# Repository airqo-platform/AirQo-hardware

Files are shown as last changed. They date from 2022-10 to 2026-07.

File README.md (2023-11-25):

# AirQo-hardware
The AirQo air qaulity monitoring device is an IoT connected device that provides realtime measurement of particualte matter concetrations and environmental readings (atmospheric pressure, relative humidity and temperature). the devices is powered by a Li-ion battery and connects to the iinternet over a 2g GSM network.
## Folder Structure
-[**Firmware**](./firmware)
    -Contains the various firmware projects for AirQo hardware, specific to different build environments
-[**Hardware**](./hardware)
    -Contains the hardware designs for AirQo hardware, 3d modesl for 3d printing, Schematic and PCB designs
-[**docs**](./docs)
    -Contains relevant documentations and templates
## Hardware design
The device is currently designed around an [Atmega2560](https://ww1.microchip.com/downloads/aemDocuments/documents/OTH/ProductDocuments/DataSheets/ATmega640-1280-1281-2560-2561-Datasheet-DS40002211A.pdf) microcontroller, that hosts the device firmware.
### block diagram 
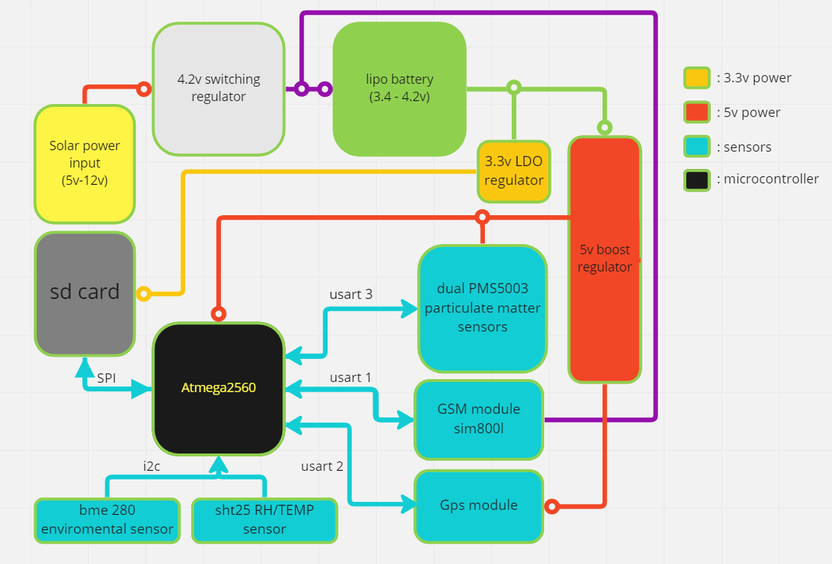
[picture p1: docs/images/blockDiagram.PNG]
block diagram

### Sensors
*Particulate matter sensors [Plantower Pms5003]()

*Environmenatal sensors     [BME280](),[SHT25]()

*GPS                        [NEO6-GPS-module]()

*Communication              [Sim800l-GSM-GPRS]()

### CAD tools
list of tolls used to design the airqo monitor
pcb tools, 3d tools, links to design files here on github
f
## Firmware design
### developed with cpp and arduino framework
The firmware provides the airqo monitor with a number of features
*Realtime measurements of particualte matter concetrations
*Logging of data to local storage
*Over The Air Firmware Updates (OTA)
## License
This project is licensed under the MIT License - see the [LICENSE.md](LICENSE.md) file for details

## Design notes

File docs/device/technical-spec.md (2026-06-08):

# Technical Specification

---

## 1. General Technical Specifications

| Parameter | Value |
|---|---|
| **Main Controller** | ATMEGA2560 |
| **Storage** | 256KB built-in, expandable to 32GB with external SD-Card |
| **RAM** | 2KB |
| **Battery** | 3240 mAh |
| **Charging** | Solar panel input 5–12V · 5V USB micro input |
| **Connectivity** | 2G GSM, Wi-Fi, LoRaWAN |
| **Dimensions** | 147.5 × 71.5 × 7.4 mm |
| **Weight** | 172 g |

!!! note
    These specifications are subject to change based on product updates and variations.

---

## 2. Electrical Specification

| Parameter | Value |
|---|---|
| **Input Voltage** | 5–12V |
| **Battery** | 3.7V LiPo 3.5AH *(solar-powered monitors)* · 3.7V Li-ion 8.8AH *(mobile monitors)* |
| **Power consumption** | 1.1W normal use · 0.098W save mode |
| **Current Draw** | 220mA normal use · 19.6mA save mode · 300mA during transmission |
| **Solar Panel** | 6W max power · 1.2A operating current · 5V operating voltage · 1.15A open circuit current · 6V open circuit voltage |

---

## 3. Communication Interfaces

| Parameter | Value |
|---|---|
| **Technology & Frequency** | Quad-band GSM/GPRS 2G — GSM 850MHz, EGSM 900MHz, DCS 1800MHz, PCS 1900MHz |
| **Data Accessibility** | AirQo Dashboard · AirQo API · AirQo App |

---

## 4. Technical Drawings

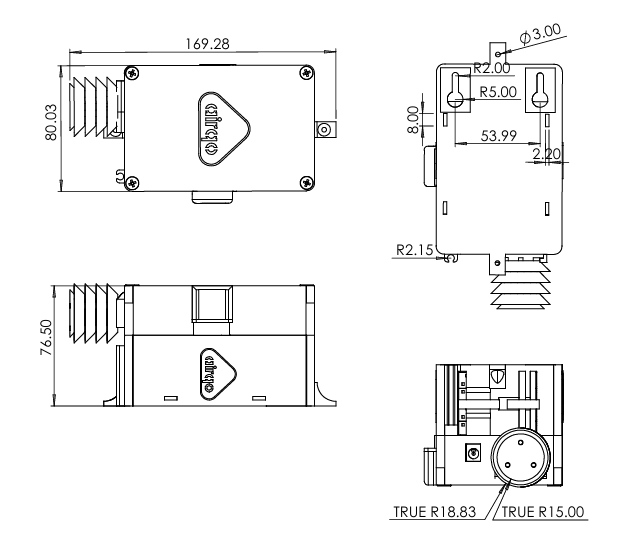
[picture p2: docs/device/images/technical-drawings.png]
Technical Drawings


For detailed PCB schematics and 3D models, see the [hardware folder](https://github.com/airqo-platform/AirQo-hardware/tree/main/hardware) in the repository.

---

## Related Pages

- [Device Overview](overview.md) — Device features and air quality measurement specs
- [Firmware Overview](../firmware/overview.md) — Firmware architecture

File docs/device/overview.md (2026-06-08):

# Device Overview

> **Tags:** Onboarding, Technical Support

---

## Know Your Monitor

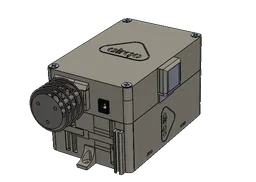
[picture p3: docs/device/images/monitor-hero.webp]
AirQo Binos Air Monitor


The **Binos Air Monitor** is a low-cost air quality monitor that measures Particulate Matter PM2.5 and PM10, as well as ambient environmental parameters (temperature and humidity). The device is designed for deployment in urban and peri-urban environments to deliver real-time air quality data to the AirQo analytics platform.

The monitors are optimized with capabilities to cope with challenges like extreme weather conditions including high levels of dust, humidity and temperature fluctuations common in Sub-Saharan Africa.

Powered by either mains or solar, the device is optimized to work in settings characterized by unreliable power and internet connectivity.

---

## Main Features

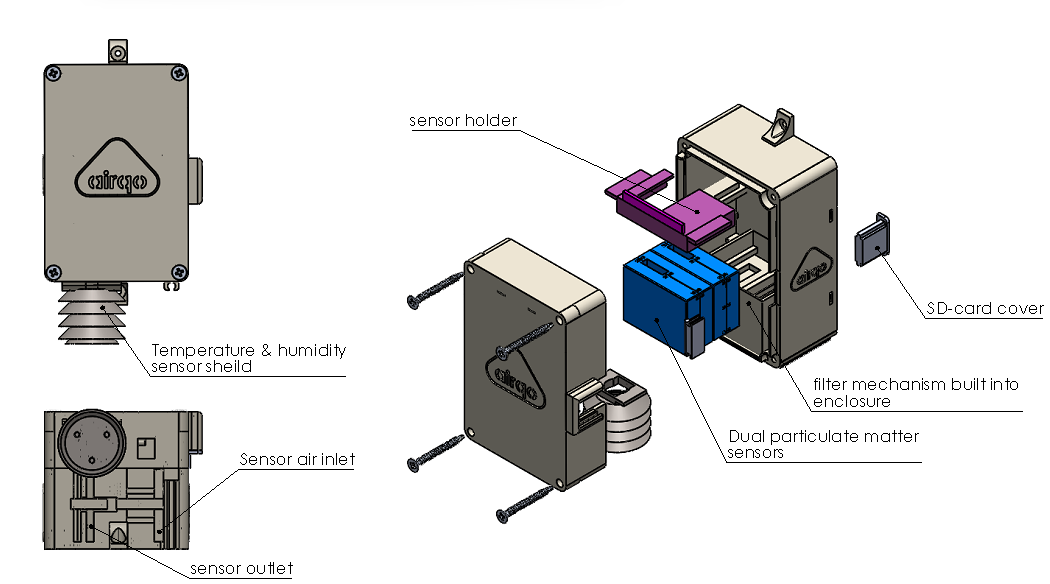
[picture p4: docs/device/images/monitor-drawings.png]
AirQo Monitor Drawings


| Feature | Detail |
|---|---|
| **Main Controller** | ATMEGA2560 |
| **Storage** | 256KB built-in, expandable to 32GB via micro SD-Card |
| **RAM** | 2KB |
| **Battery** | 3240 mAh |
| **Charging** | Solar panel input 5–12V · 5V USB micro input |
| **Connectivity** | 2G GSM, Wi-Fi, LoRaWAN |
| **Dimensions** | 147.5 × 71.5 × 7.4 mm (5.8 × 2.8 × 0.3 in) |
| **Weight** | 172 g (6.07 oz) |

---

## Air Quality Measurements

| Parameter | Specification |
|---|---|
| **Particulate matter range** | 0.3–1.0 μm · 1.0–2.5 μm · 2.5–10 μm |
| **Effective range (PM2.5)** | 0–500 μg/m³ |
| **Maximum range (PM2.5)** | < 1000 μg/m³ |
| **Consistency (PM2.5)** | ±10% @ 100–500 μg/m³ · ±10 μg/m³ @ 0–100 μg/m³ |
| **Standard volume/flow** | 0.1 L |
| **Single response time** | < 1 s |
| **Data resolution** | 60–90 seconds |

---

## Related Pages

- [Technical Specification](technical-spec.md) — Full hardware specifications
- [Firmware Overview](../firmware/overview.md) — How the firmware operates
- [Deployment](../deployment.md) — How to deploy and access data

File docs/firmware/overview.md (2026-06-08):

# Firmware Overview

Robustly developed firmware enables efficient operation of the device to deliver the best data availability and quality to the users. This section covers the key firmware features and how they work.

---

## Key Firmware Features

### Sensor Sampling

The device obtains meteorological (temperature and humidity) and other sensing parameters like particulate matter and battery voltage using different sensor modules. Parameters sampled include:

- PM2.5
- PM10
- Temperature
- Humidity
- Battery voltage

### SD Card Data Logging

The data obtained from the sensors is logged onto a micro SD card in CSV file format with the necessary parameters to be sent to the cloud storage. This ensures data is not lost even when network connectivity is unavailable.

See [SD Card Data Organization](sd-card.md) for details on how data files are structured.

### Automatic Time Tracking

Device firmware utilizes a Real Time Clock (RTC) to track the date and time with accuracy. A backup battery powers the RTC to provide time tracking even when the main battery is depleted.

The RTC time domain informs the following parameters:

- Local filenames stored on the SD card (based on time of creation)
- Device data timestamps (based on the time of writing to the SD-card file)

### Transmission Failure Handling

The device firmware incorporates data transmission failure handling by buffering data entries that have failed in transmission to a backup file and scheduling retransmission. This ensures no data loss during periods of poor connectivity.

---

## Firmware Variants

| Variant | Description | Folder |
|---|---|---|
| **AirQo Rev C** | Standard production firmware (GSM/GPRS) | [`airqo_rev_c_firmware`](https://github.com/airqo-platform/AirQo-hardware/tree/main/firmware/airqo_rev_c_firmware) |
| **LoRaWAN v1** | For LoRaWAN network deployments | [`lorawan_firmware_v1`](https://github.com/airqo-platform/AirQo-hardware/tree/main/firmware/lorawan_firmware_v1) |
| **MQTT / ThingSpeak** | For MQTT-based integrations | [`mqtt_thingspeak_bi_directional_communication`](https://github.com/airqo-platform/AirQo-hardware/tree/main/firmware/mqtt_thingspeak_bi_directional_communication) |

---

## Related Pages

- [SD Card Data Organization](sd-card.md)
- [Firmware Configuration](configuration.md)
- [Technical Specification](../device/technical-spec.md)
- [Deployment](../deployment.md)

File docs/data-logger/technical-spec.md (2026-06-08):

# Data Logger — Technical Specification

---

## General

| Parameter | Value |
|---|---|
| **Certifications** | None |
| **Dimensions** | 112.85 × 55.18 × 54.86 mm |
| **Weight** | 215.5 g |
| **Deployment setting** | Outdoor / ambient conditions |
| **Operating temperature** | 0–45 °C |

!!! warning
    Not compatible with fire, flames, or immersion in water.

---

## Host Interface

| Port | Type |
|---|---|
| CS I/O communications port | — |
| RS-232 serial port | DB9 male |
| RS-485 serial port | DB9 female |
| USB | Version 2.0 with USB-C connector |

---

## Power

| Parameter | Value |
|---|---|
| **Input voltage** | 5–12V |
| **Battery** | 3.7V Li-ion 3.5AH |
| **Power — Active** | 1.1W |
| **Power — Save mode** | 0.098W |
| **Current draw — Normal use** | 220mA |
| **Current draw — Save mode** | 19.6mA |
| **Current draw — Transmission** | 300mA |

---

## Cellular Communication

| Parameter | Value |
|---|---|
| **Network technology** | Quad-band GSM/GPRS 2G |
| **Frequencies** | GSM/GPRS 850MHz · GSM EDGE 900MHz · DCS 1800MHz · PCS 1900MHz |
| **Data accessibility** | AirQo Dashboard · AirQo API · AirQo App |

---

## Data Speeds

| Technology | Download | Upload |
|---|---|---|
| LTE | Max 10 Mbps | Max 5 Mbps |
| WCDMA | Max 384 Kbps | Max 384 Kbps |
| GSM GPRS | Max 107 Kbps | Max 85.6 Kbps |
| GSM EDGE | Max 296 Kbps | Max 236.8 Kbps |
| RS-232 / RS-485 | 9600 bps – 460.8 Kbps | 9600 bps – 460.8 Kbps |

---

## Technical Drawings

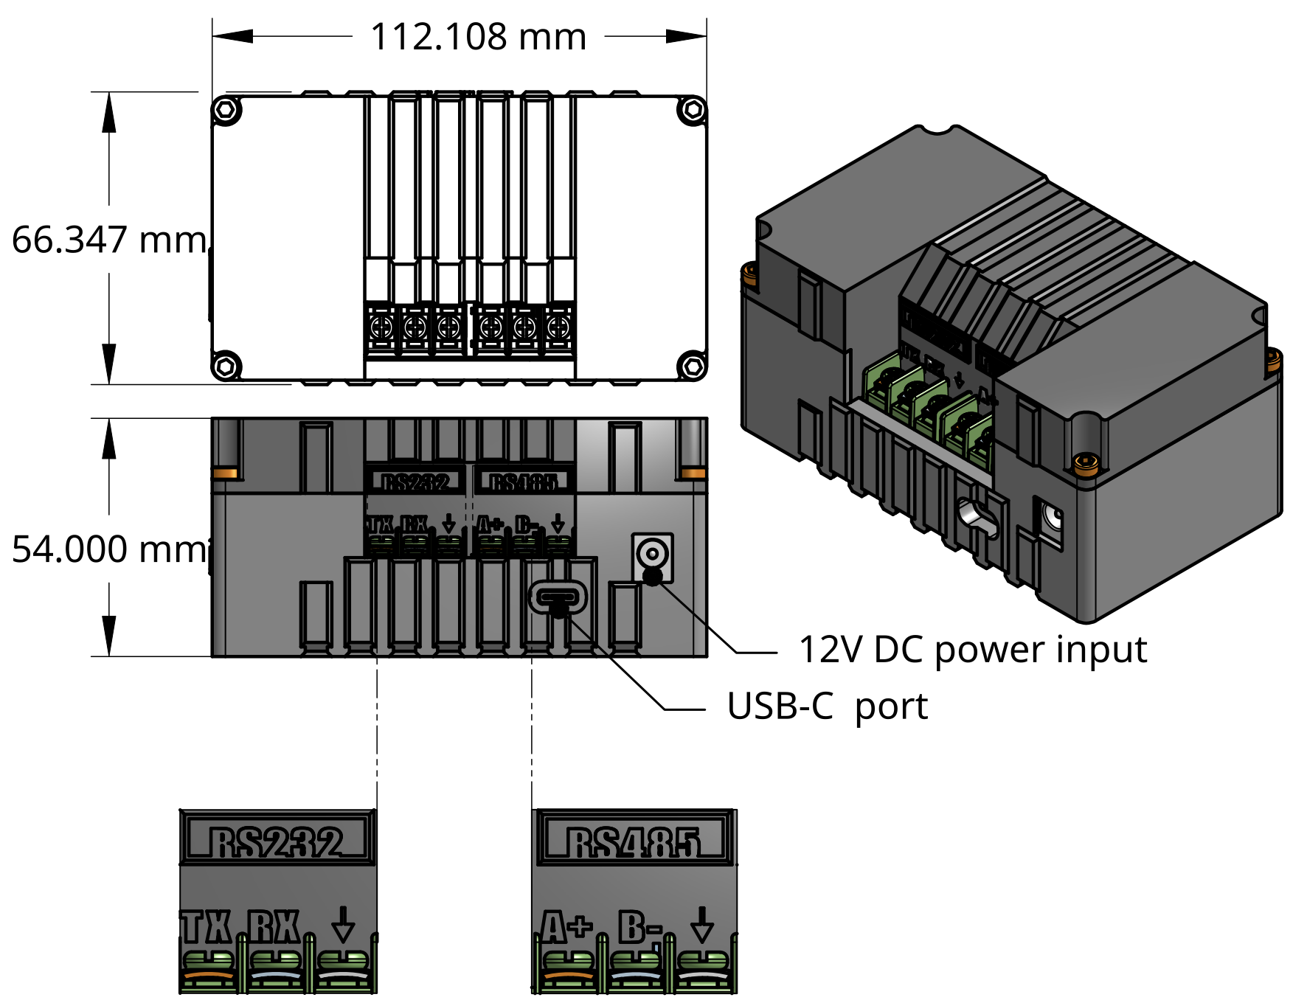
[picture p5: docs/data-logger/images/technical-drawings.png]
Technical Drawings


---

## Related Pages

- [Data Logger Overview](index.md)
- [Installation](installation.md)
- [Data Access](data-access.md)

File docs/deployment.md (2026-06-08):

# Deployment Guide

This provides information on how to deploy the AirQo device onto the AirQo analytics platform successfully. This section guides on installing the monitor using the included toolkit. Mounting equipment for pole, wall, or face installation is provided along with step-by-step guidance.

---

## Installation Toolkit

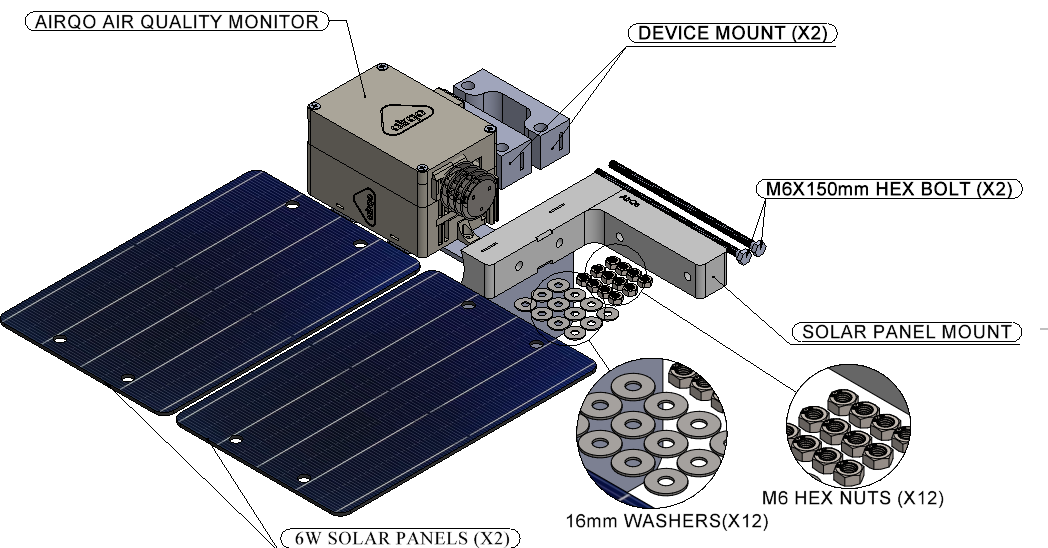
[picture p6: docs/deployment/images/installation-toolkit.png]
Installation Toolkit


The installation kit includes:

- Device carrier brackets
- Mounting bolts, washers, and nuts
- Pole/wall mounting hardware
- Tool kit for assembly

---

## Installation Site Selection Guidelines

When selecting an installation site, consider:

| Factor | Guideline |
|---|---|
| **Height** | Mount at 2–5 metres above ground level |
| **Airflow** | Avoid locations blocked by walls or vegetation |
| **Sun exposure** | Solar panel must face direction of maximum sunlight |
| **Network** | Verify 2G GSM signal available at the site |
| **Security** | Choose a location that minimises risk of tampering |

---

## Installation Procedure

!!! warning
    Ensure the device is powered off before mounting.

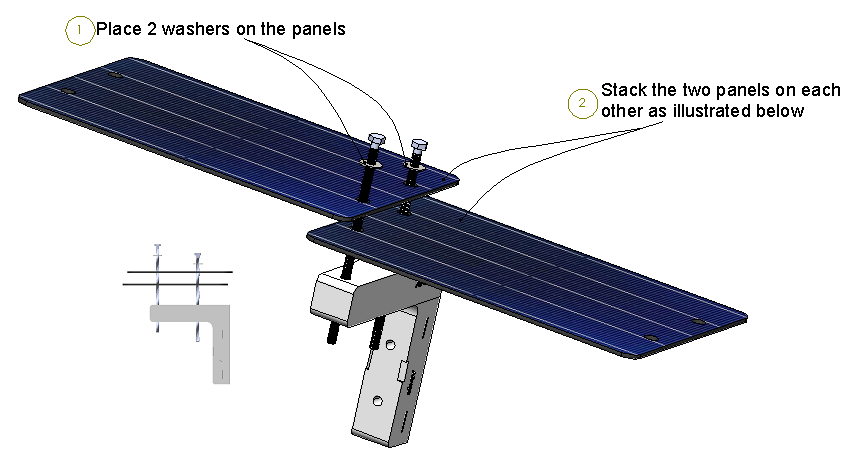
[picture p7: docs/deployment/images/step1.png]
Installation Step 1


**Step 1:** Attach the first device carrier to the mounting pole and fasten securely.

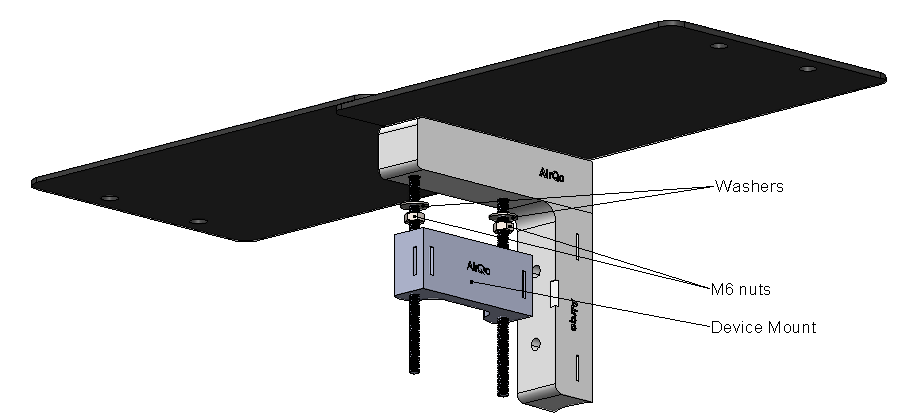
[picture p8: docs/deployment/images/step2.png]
Installation Step 2


**Step 2:** Measure approximately 5cm after the first device carrier, then attach the second device carrier and fasten with two washers and 2 nuts.

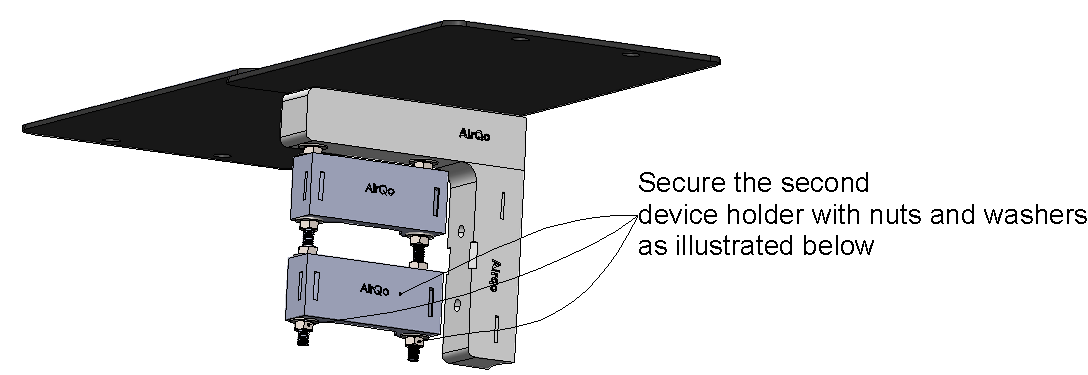
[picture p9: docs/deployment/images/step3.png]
Installation Step 3


**Step 3:** Mount the AirQo monitor onto the assembled carrier brackets.

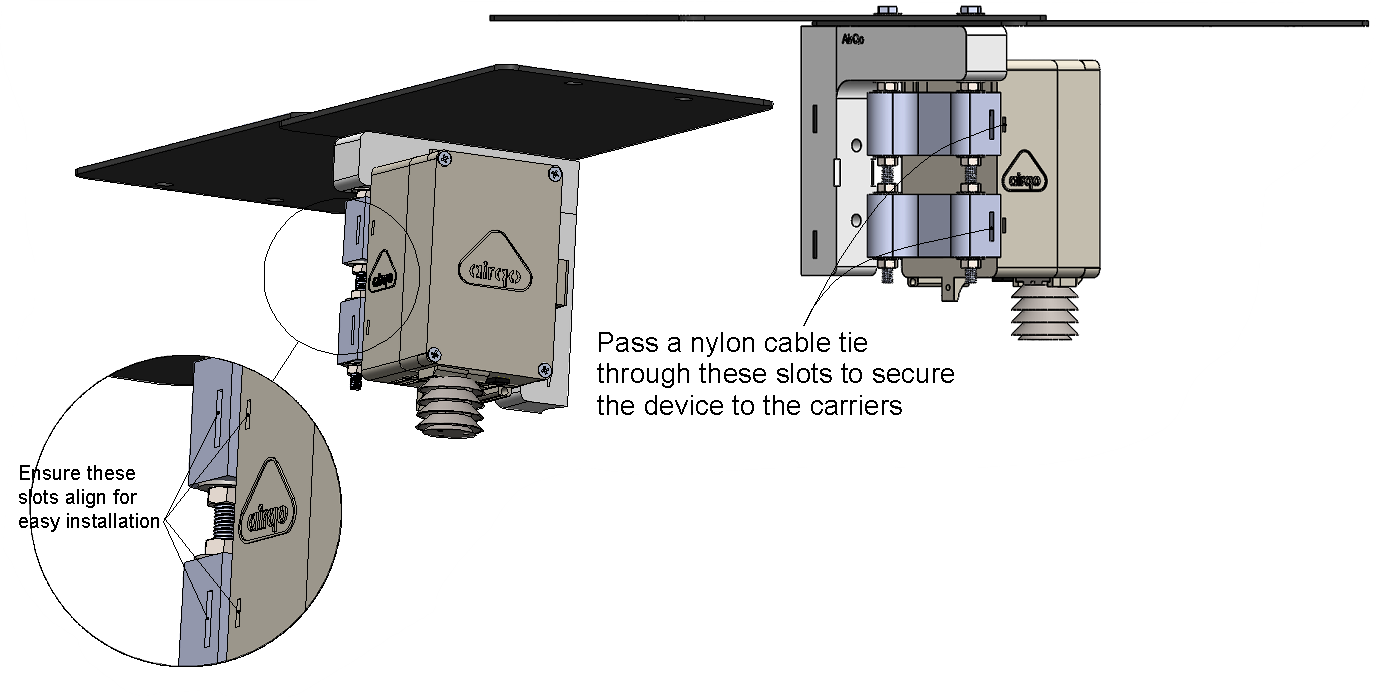
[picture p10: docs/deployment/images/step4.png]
Installation Step 4


**Step 4:** After assembly, verify the device is securely mounted and the solar panel is correctly oriented.

Assembled Device

!!! tip
    After assembly, the device should be stable with the solar panel unobstructed and sensors exposed to ambient air.

---

## Data Access

### Creating an Account

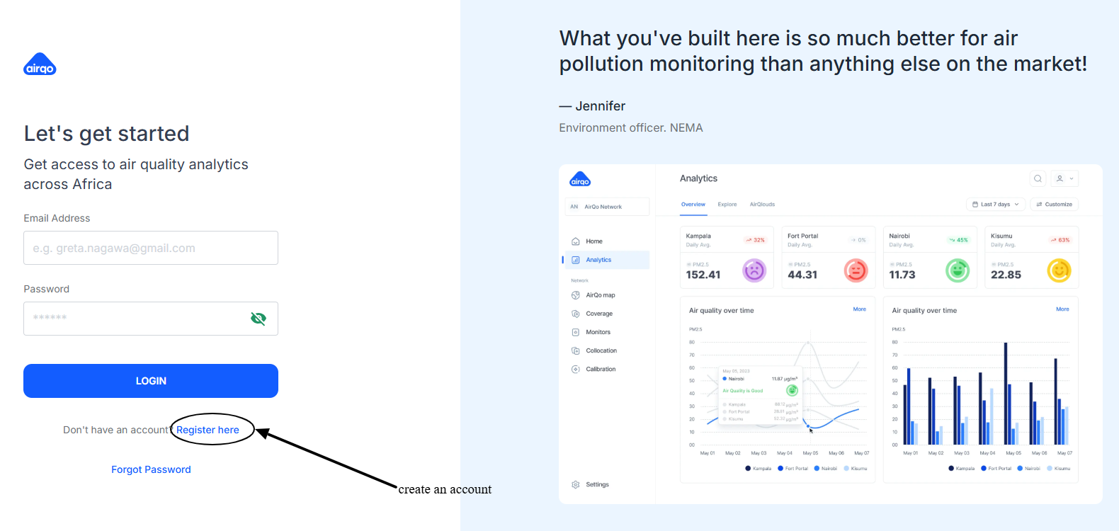
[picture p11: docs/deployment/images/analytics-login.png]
AirQo Analytics Login


Visit the [AirQo Analytics Platform](https://analytics.airqo.net) and click **Register**. You will receive an email to verify your account.

### Accessing Analytics

After logging in, navigate to the **Analytics** option on the left side of the Dashboard.

### Adding a Location

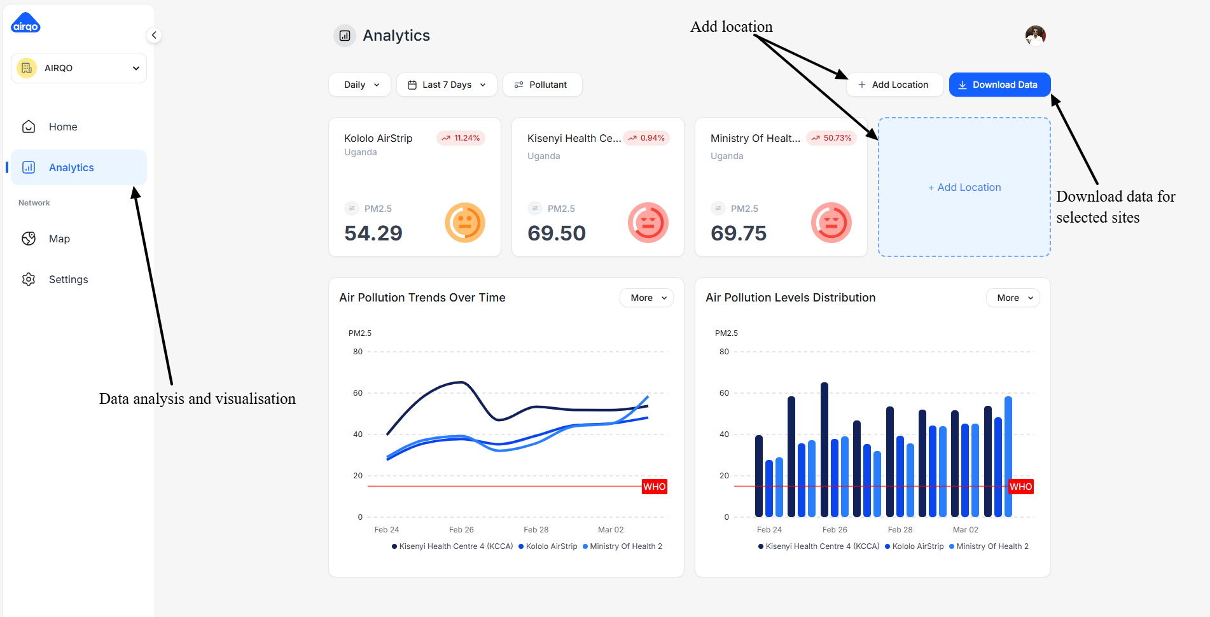
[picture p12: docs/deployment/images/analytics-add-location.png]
Add Location


Under the **Analytics** tab, click **Add Location** to register your deployment site.

### Viewing Real-Time Data

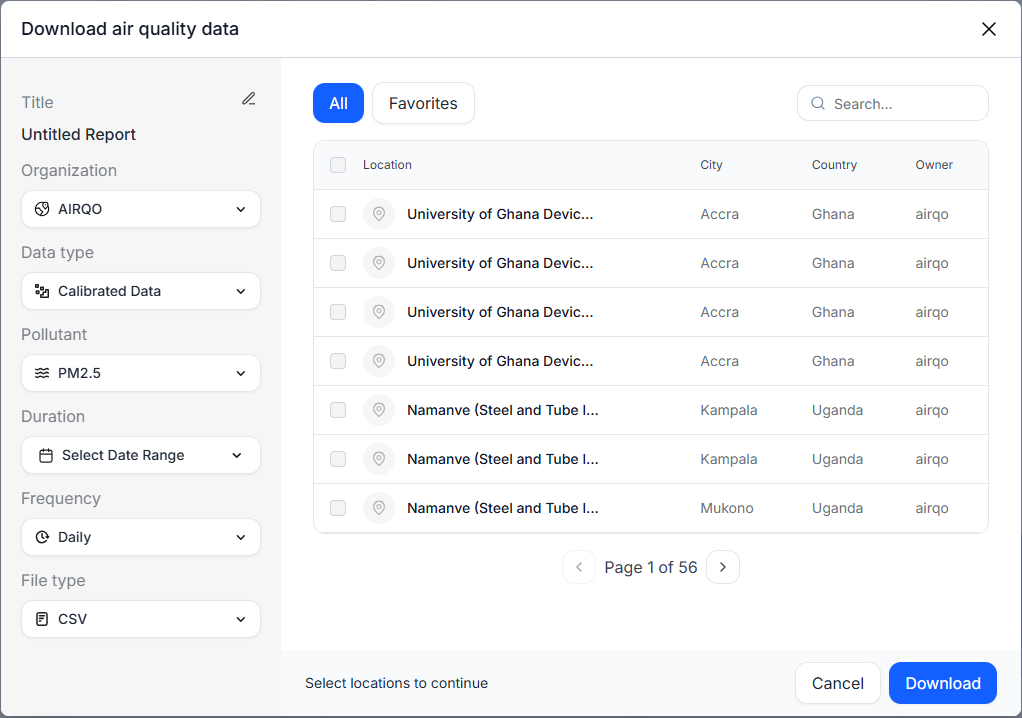
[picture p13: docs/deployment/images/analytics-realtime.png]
Real-Time Analytics


Select a maximum of **4 sites** to view their data in real time. Highlight the site locations you want to visualise.

---

## Related Pages

- [Device Overview](device/overview.md) — Understanding what the device measures
- [Technical Specification](device/technical-spec.md) — Hardware specifications
- [Maintenance](maintenance/index.md) — Keeping the device running optimally

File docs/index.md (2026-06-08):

---
layout: home

hero:
  name: "AirQo"
  text: "Hardware Documentation"
  tagline: Binos Air Quality Monitor · BAM Data Logger · Firmware · Deployment
  image:
    src: /airqo-logo.png
    alt: AirQo Logo
  actions:
    - theme: brand
      text: Get Started
      link: /device/overview
    - theme: alt
      text: Data Logger
      link: /data-logger/
    - theme: alt
      text: View on GitHub
      link: https://github.com/airqo-platform/AirQo-hardware

features:
  - icon: 🌍
    title: Device Overview
    details: What is the Binos Air Monitor, key features, PM2.5/PM10 measurements, GPS, and connectivity.
    link: /device/overview
  - icon: 📐
    title: Technical Specification
    details: Hardware specs, electrical interfaces, communication protocols, and sensor datasheets.
    link: /device/technical-spec
  - icon: ⚙️
    title: Firmware
    details: How the firmware works, sensor sampling, data logging, SD card layout, and OTA updates.
    link: /firmware/overview
  - icon: 🚀
    title: Deployment
    details: Step-by-step installation guide, site selection, mounting, and platform data access.
    link: /deployment
  - icon: 🔧
    title: Maintenance
    details: Routine maintenance schedule, toolkit, fault diagnosis, and system upkeep procedures.
    link: /maintenance/
  - icon: 📊
    title: BAM Data Logger
    details: TSI BAM 1022 data logger setup, RS-232/RS-485 wiring, and data retrieval guide.
    link: /data-logger/
---

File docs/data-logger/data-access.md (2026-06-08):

# Data Access & Debugging

---

## Platform Data Access

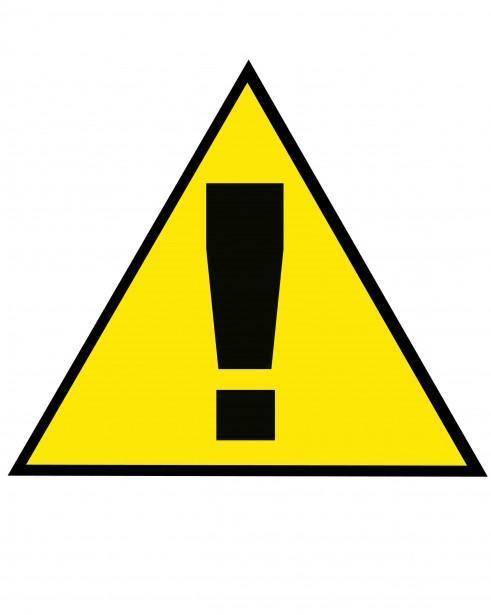
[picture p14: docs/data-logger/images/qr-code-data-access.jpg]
QR Code Data Access


The data logger is shipped with a **QR code** corresponding to the device identification details on the AirQo Analytics platform. Scan the QR code to link the device to your AirQo account and begin viewing data.

For platform setup instructions, see the [Deployment Guide](../deployment.md).

---

## Serial Data Access & Debugging

The data logger exposes a **USB-C port** that provides serial data access via a serial monitoring terminal on a computer. This is useful for verifying a successful connection and communication between the BAM1022 and the data logger.

### Steps

!!! danger "Disconnect 12V Power First"
    You **must** disconnect the 12V power cable from the BAM1022 before connecting the USB-C cable to the device and your computer for debugging and configuration.

1. Disconnect the 12V DC power cable from the BAM1022
2. Connect a USB-C cable from the data logger to your computer
3. Open a serial monitor terminal (e.g. Arduino IDE Serial Monitor, PuTTY, or `screen`)
4. Set baud rate to **9600 bps**
5. Observe the serial output to verify BAM1022 data is being received

### What to Look For

| Output | Meaning |
|---|---|
| Sensor readings appearing | BAM1022 connection is working correctly |
| No output / blank terminal | Check wiring connections (TX/RX/GND) |
| Garbled characters | Baud rate mismatch — check BAM1022 serial settings |
| Transmission confirmations | Data is being streamed to AirQo platform |

---

## Related Pages

- [Data Logger Overview](index.md)
- [Technical Specification](technical-spec.md)
- [Installation](installation.md)

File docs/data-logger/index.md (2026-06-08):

# BAM Data Logger

> **Document:** AirQo Data Logger User Manual · Feb 23, 2026

---

## Introduction

AirQo Data Logger is a remote data logging solution specifically for the **BAM1022** reference air quality monitoring system. The logger utilizes the available communication ports on the BAM1022 to periodically retrieve data from the system and stream it to AirQo data platforms.

---

## Know Your Device

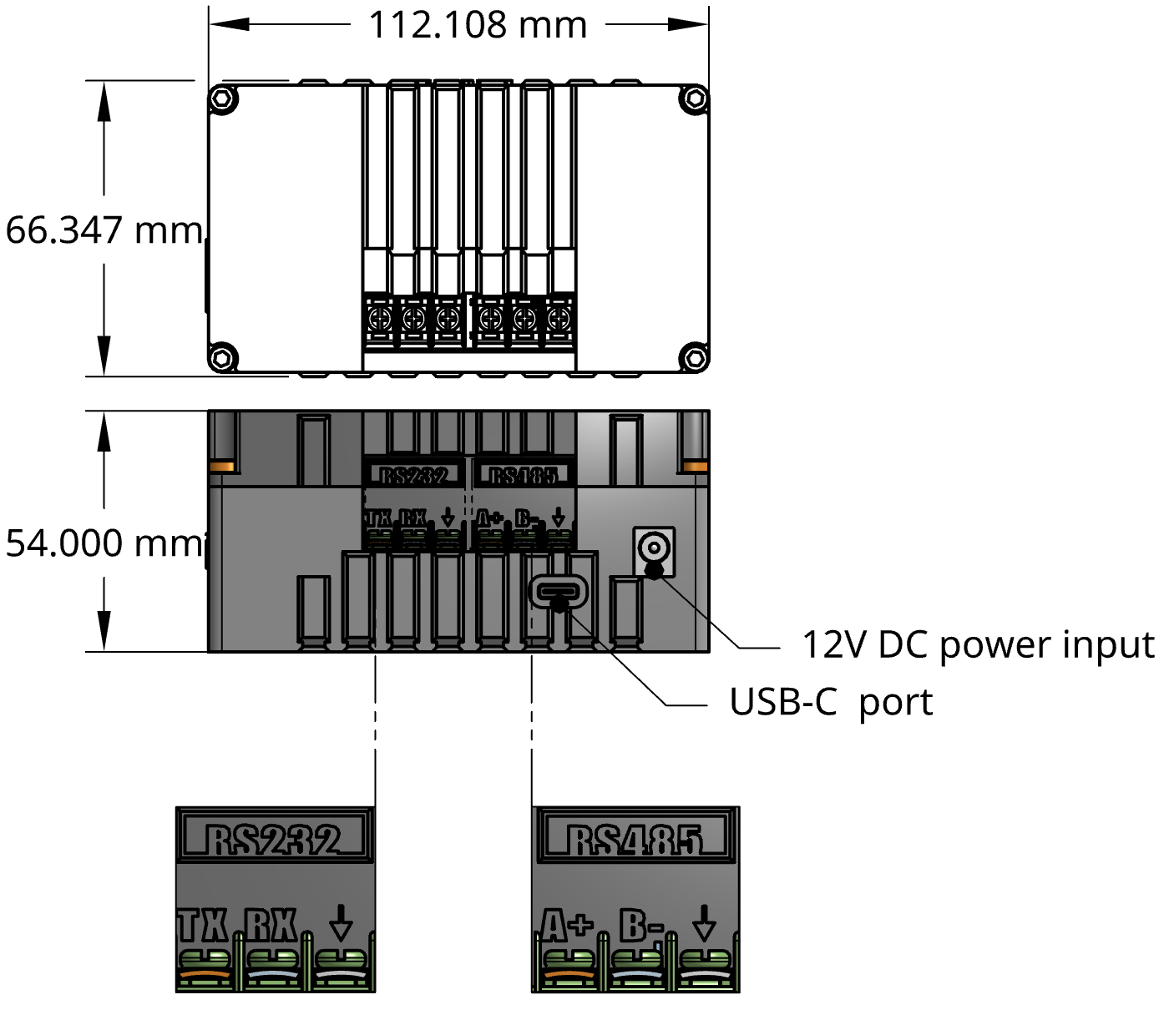
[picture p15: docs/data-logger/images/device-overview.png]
AirQo Data Logger


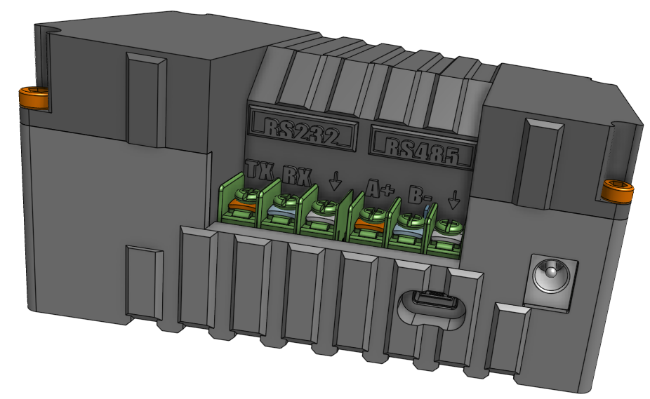
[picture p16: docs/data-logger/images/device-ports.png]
Data Logger Ports


The AirQo Data Logger is a compact enclosure that mounts alongside the BAM1022. It exposes several communication interfaces on its breakout panel:

| Interface | Connector |
|---|---|
| CS I/O communications port | — |
| RS-232 serial port | DB9 male |
| RS-485 serial port | DB9 female |
| USB serial / debug | USB-C |
| DC Power input | Barrel connector |

---

## Quick Links

| Section | Description |
|---|---|
| [Technical Specification](technical-spec.md) | Dimensions, power, cellular and data specs |
| [Installation](installation.md) | Connecting to the BAM1022, wiring, and powering |
| [Data Access](data-access.md) | Accessing data via AirQo platform and serial debug |

---

## Related Pages

- [Device Overview](../device/overview.md) — AirQo Binos Air Monitor
- [Deployment](../deployment.md) — General deployment guidance

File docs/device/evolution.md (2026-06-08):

# Hardware Evolution

6 generations and counting — what started out as a simple breadboard prototype has evolved through the years. Here we take a look at the evolution of AirQo hardware.

---

## Hardware Generations

| Generation | Key Milestone |
|---|---|
| **Gen 1** | Initial breadboard prototype — proof of concept |
| **Gen 2** | First PCB design, basic PM2.5 sensing |
| **Gen 3** | Added GSM connectivity and cloud data upload |
| **Gen 4** | Solar power integration, improved enclosure |
| **Gen 5** | ATMEGA2560-based design, multi-sensor, LoRaWAN support |
| **Gen 6+** | Ongoing improvements in accuracy, power efficiency, and connectivity |

---

## Design Files

Hardware design files for current and previous generations are available in the [hardware folder](https://github.com/airqo-platform/AirQo-hardware/tree/main/hardware) of the repository, including:

- PCB schematics (KiCad)
- Gerber files for PCB manufacturing
- 3D enclosure designs for 3D printing

---

## Related Pages

- [Device Overview](overview.md) — Current device features
- [Technical Specification](technical-spec.md) — Current hardware specifications

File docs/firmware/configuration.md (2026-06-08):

# Firmware Configuration

---

This page covers how to configure the AirQo device firmware for your deployment environment.

## Configuration Parameters

The firmware exposes several configurable parameters that can be set before flashing or via runtime configuration:

| Parameter | Description |
|---|---|
| **Network APN** | GSM/GPRS APN for your SIM provider |
| **Server endpoint** | URL of the AirQo data ingestion API |
| **Device ID** | Unique identifier for this monitor unit |
| **Sampling interval** | How often sensor readings are taken (default: 60–90s) |
| **Transmission interval** | How often data is sent to the cloud |
| **RTC sync** | Enable/disable time sync via GSM network |

## Flashing the Firmware

The firmware is developed with C++ using the Arduino framework.

**Prerequisites:**

- [Arduino IDE](https://www.arduino.cc/en/software) or [PlatformIO](https://platformio.org/)
- USB cable (Micro USB)
- Board: **Arduino Mega (ATMEGA2560)**

**Steps:**

1. Clone the repository and open the relevant firmware project folder
2. Configure parameters in the config header file
3. Connect the device via USB
4. Select board: **Arduino Mega (ATMEGA2560)**
5. Upload

!!! warning
    Ensure the device is powered off from its main supply before connecting via USB for flashing.

## Firmware Variants

| Variant | Folder |
|---|---|
| AirQo Rev C (standard) | [`airqo_rev_c_firmware`](https://github.com/airqo-platform/AirQo-hardware/tree/main/firmware/airqo_rev_c_firmware) |
| LoRaWAN v1 | [`lorawan_firmware_v1`](https://github.com/airqo-platform/AirQo-hardware/tree/main/firmware/lorawan_firmware_v1) |
| MQTT / ThingSpeak | [`mqtt_thingspeak_bi_directional_communication`](https://github.com/airqo-platform/AirQo-hardware/tree/main/firmware/mqtt_thingspeak_bi_directional_communication) |

---

## Related Pages

- [Firmware Overview](overview.md) — Key firmware features
- [SD Card Data Organization](sd-card.md) — SD card data structure

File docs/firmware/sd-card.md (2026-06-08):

# SD Card Data Organization

---

The AirQo device logs sensor readings to a micro SD card in CSV format. File organization follows a time-based naming convention driven by the onboard Real Time Clock (RTC).

## File Naming Convention

Files are created and named based on:

- **Time of creation** — a new file is created at the start of each logging session
- **Time of writing** — timestamps embedded in each CSV row reflect the exact time data was written to the SD card

## CSV Data Format

Each row in the CSV log file contains the following fields:

| Field | Description |
|---|---|
| Timestamp | Date and time from RTC |
| PM2.5 | Particulate matter 2.5 μm reading (μg/m³) |
| PM10 | Particulate matter 10 μm reading (μg/m³) |
| Temperature | Ambient temperature (°C) |
| Humidity | Relative humidity (%) |
| Battery Voltage | Current battery level (V) |

## Transmission Backup

When transmission to the cloud fails, undelivered data entries are buffered to a backup file on the SD card. The firmware automatically retries transmission of buffered data when connectivity is restored.

---

## Related Pages

- [Firmware Overview](overview.md) — Overview of all firmware features
- [Firmware Configuration](configuration.md) — Configuring the device firmware

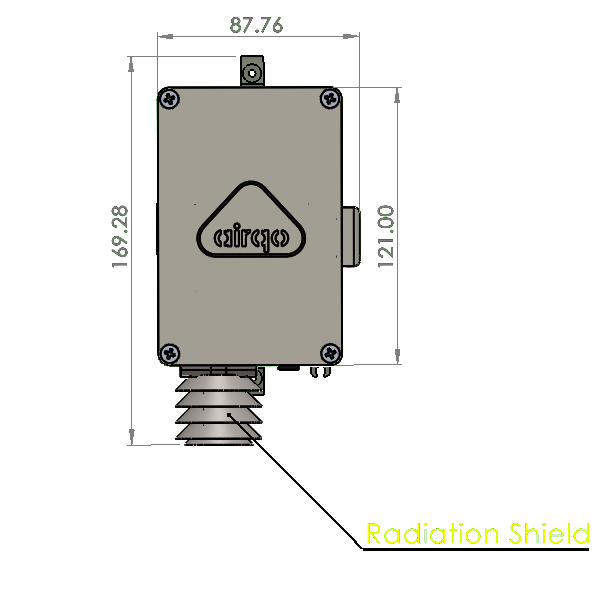
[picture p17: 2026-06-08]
docs/device/images/tech-spec-cover.png

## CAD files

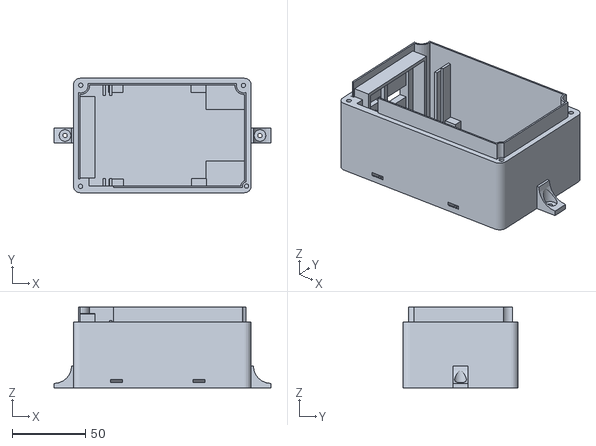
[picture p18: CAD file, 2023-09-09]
hardware/enclosure_designs/gen5_revb_2_casing_files/main_body.stl
147.8 x 78.0 x 55.0

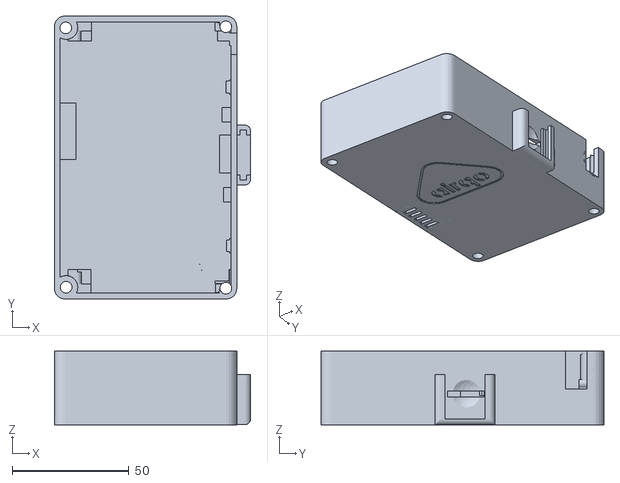
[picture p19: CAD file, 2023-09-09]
hardware/enclosure_designs/gen5_revb_2_casing_files/main_cover.stl
83.9 x 121.0 x 31.5

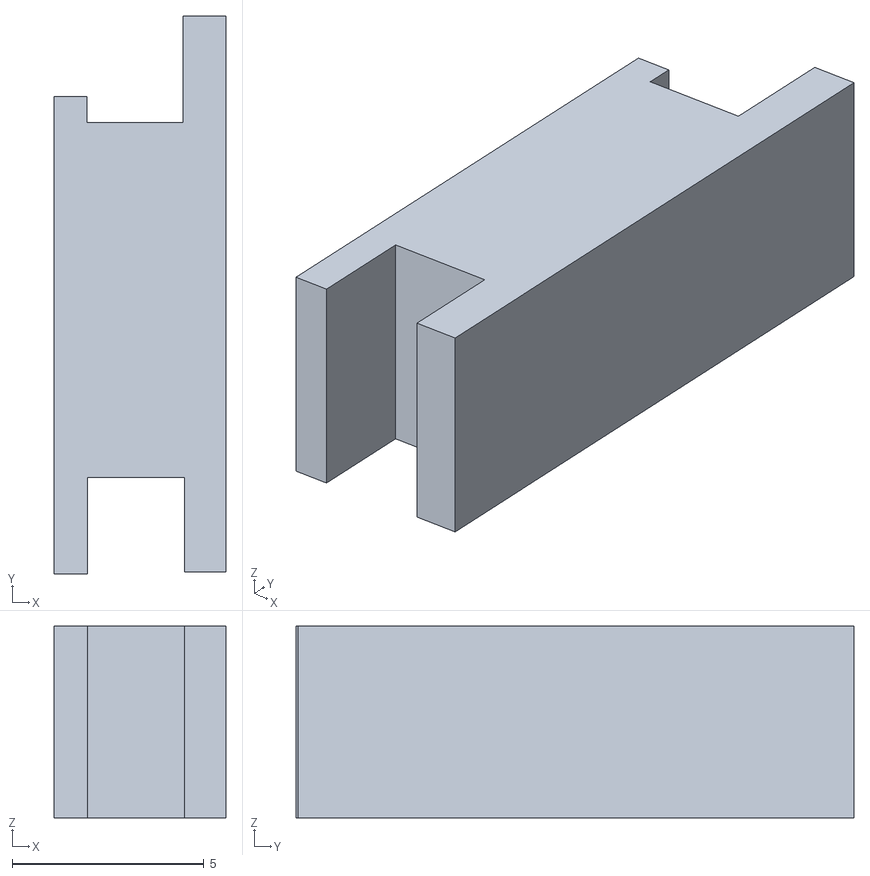
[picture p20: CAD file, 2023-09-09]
hardware/enclosure_designs/gen5_revb_2_casing_files/power_jack_cover.stl
4.47 x 14.5 x 5.00

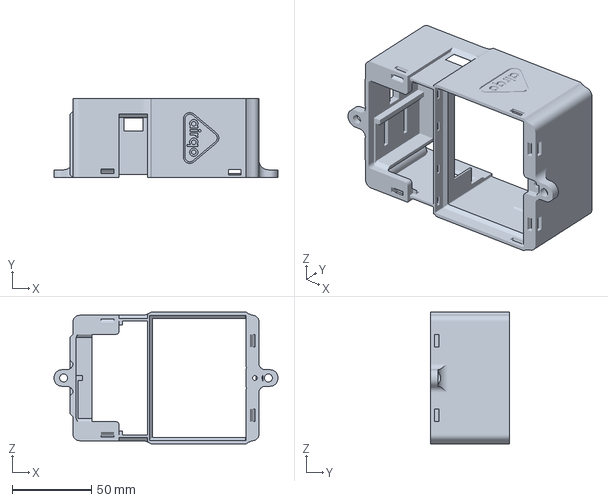
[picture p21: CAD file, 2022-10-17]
hardware/enclosure_designs/revc_enclosure/gen5revc_enclosure_body_v3.3MF
141.0 x 50.0 x 82.8 mm

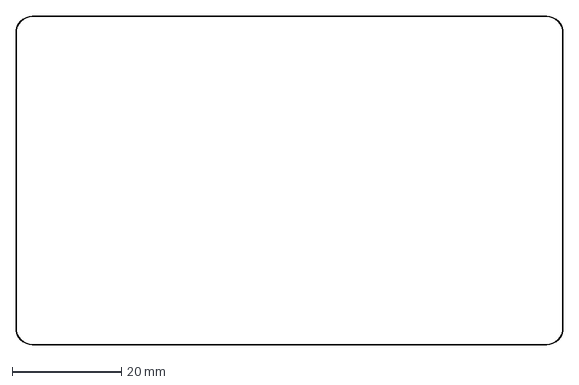
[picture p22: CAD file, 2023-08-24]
hardware/lorawan_prototype_v1.1/boardoutline.DXF
100.0 x 60.0 mm

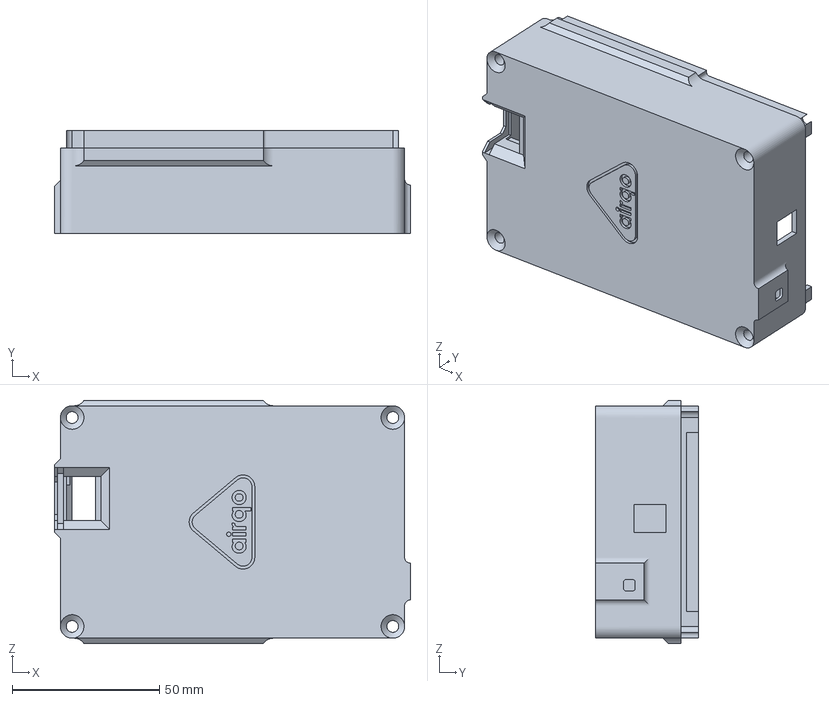
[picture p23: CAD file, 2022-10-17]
hardware/enclosure_designs/revc_enclosure/gen5revc_enclosure_v3.3MF
121.0 x 35.0 x 82.6 mm

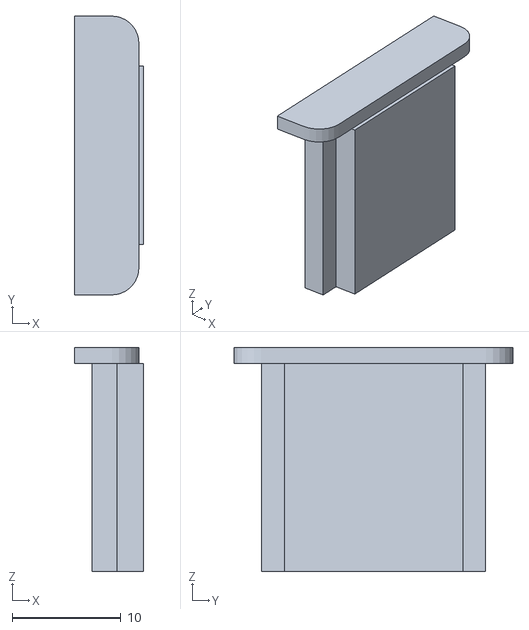
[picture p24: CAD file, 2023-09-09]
hardware/enclosure_designs/gen5_revb_2_casing_files/sd_cover.stl
6.31 x 25.6 x 20.6

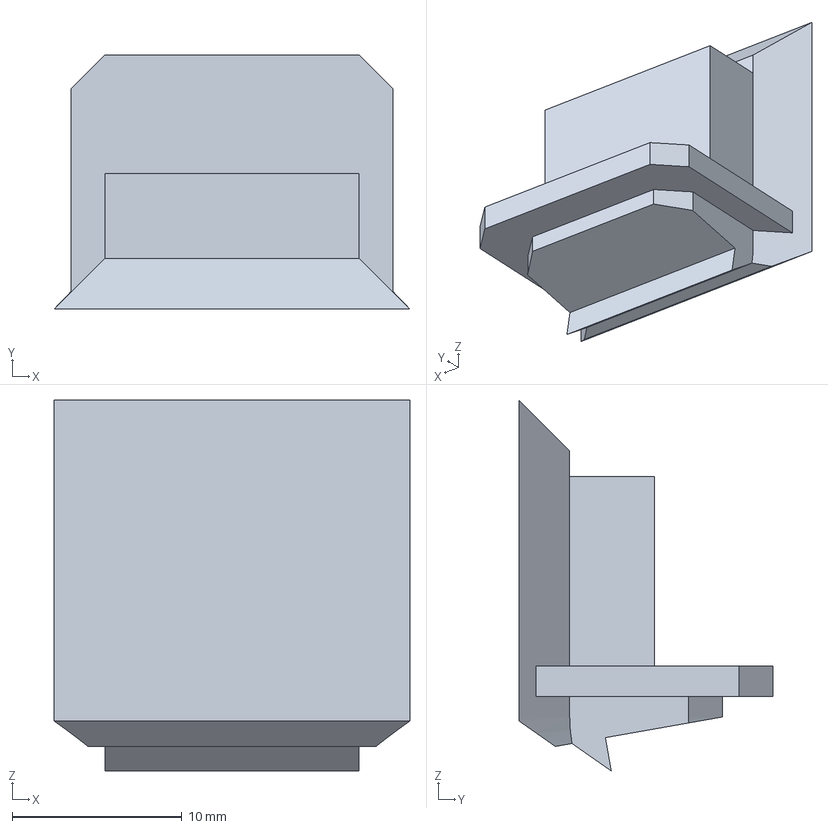
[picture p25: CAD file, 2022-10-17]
hardware/enclosure_designs/revc_enclosure/gen5revc_sdcard_plug_v3.3MF
21.0 x 15.0 x 21.9 mm

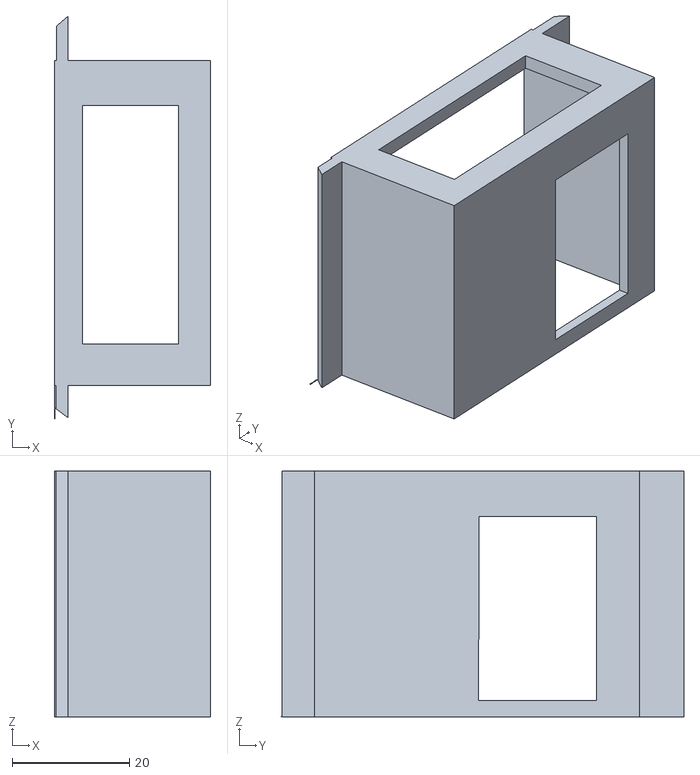
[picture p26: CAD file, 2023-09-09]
hardware/enclosure_designs/gen5_revb_2_casing_files/pm_sensor_holder.stl
26.7 x 68.8 x 42.0

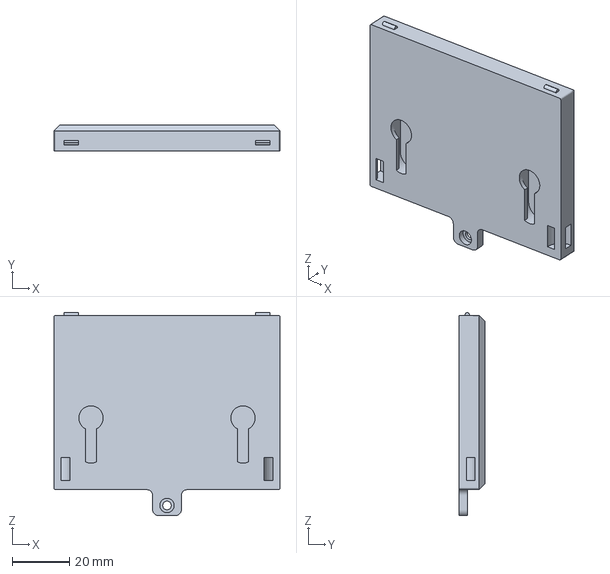
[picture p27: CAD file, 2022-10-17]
hardware/enclosure_designs/revc_enclosure/gen5revc_battery_cover_v3.3MF
78.8 x 9.00 x 70.8 mm

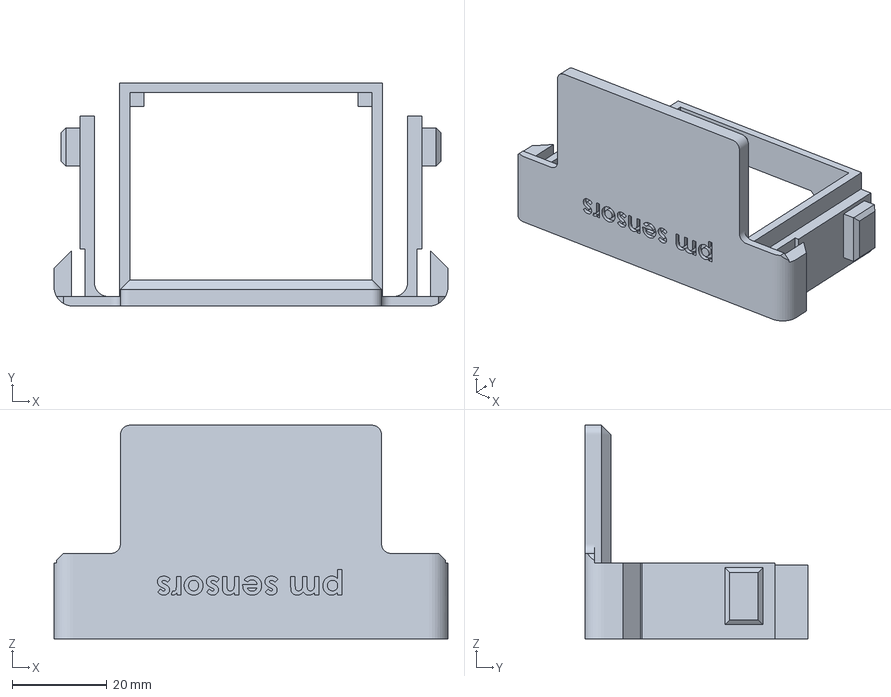
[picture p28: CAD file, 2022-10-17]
hardware/enclosure_designs/revc_enclosure/gen5revc_sensor_carier_v3.3MF
83.0 x 47.0 x 45.0 mm

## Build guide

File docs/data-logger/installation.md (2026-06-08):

# Installation — Connecting to the BAM1022

---

## Tools Required

1. Phillips screwdriver
2. Wire strippers / pliers
3. 5× extension wires (~30cm each) — included in the device package

---

## Connection Procedure

### Step 1 — Access the BAM1022 Back Panel

Unscrew the **4 butterfly nuts** securing the back panel of the BAM1022 to expose the power ports and external communication ports.

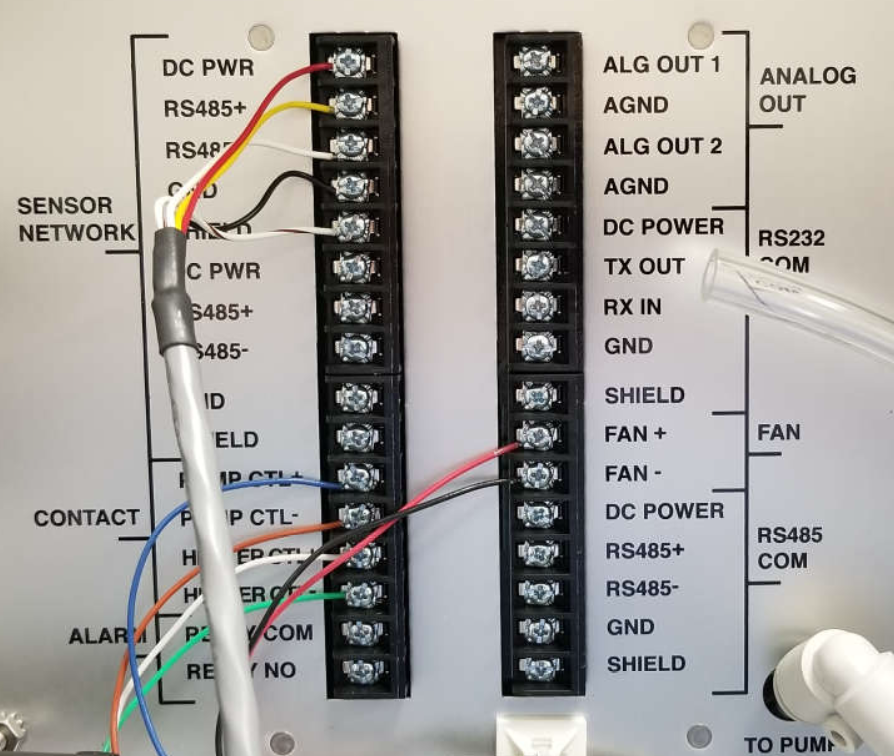
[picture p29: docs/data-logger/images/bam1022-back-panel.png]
BAM1022 Back Panel


---

## Serial Communication Connections

Make the following connections between the **BAM1022 expansion interface** and the **AirQo Data Logger communication breakout**:

| BAM1022 Expansion Interface | AirQo Data Logger |
|---|---|
| TX OUT | TX |
| RX IN | RX |
| RS485+ | A+ |
| RS485- | B- |
| GND | GND |

!!! note
    Use the supplied extension wires, cut to appropriate lengths.

---

### RS-232 Setup

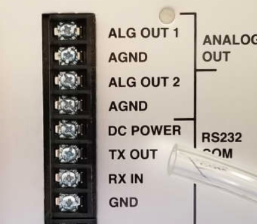
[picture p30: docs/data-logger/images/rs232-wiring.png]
RS-232 Wiring


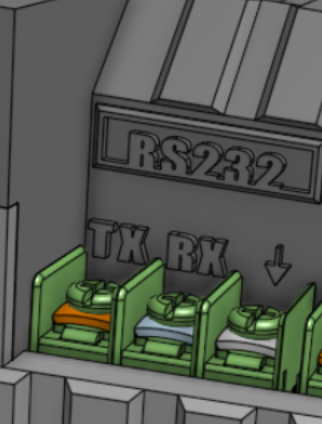
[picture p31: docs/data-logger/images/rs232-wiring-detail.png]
RS-232 Wiring Detail


Three wires are required: **GND**, **TXOUT**, and **RX IN**.

1. Connect **GND** from BAM1022 → **GND** on the data logger
2. Connect **TXOUT** from BAM1022 → **TX** on the data logger
3. Connect **RX IN** from BAM1022 → **RX** on the data logger

---

### RS-485 Setup

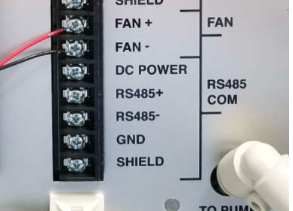
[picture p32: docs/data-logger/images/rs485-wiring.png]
RS-485 Wiring


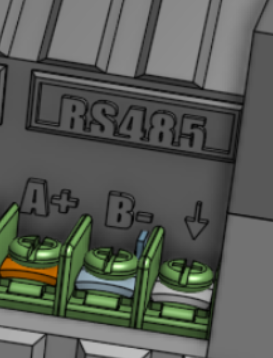
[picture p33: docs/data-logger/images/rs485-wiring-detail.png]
RS-485 Wiring Detail


Three wires are required: **GND**, **RS485+**, and **RS485-**.

1. Connect **GND** from BAM1022 → **GND** on the data logger
2. Connect **RS485+** from BAM1022 → **A+** on the data logger
3. Connect **RS485-** from BAM1022 → **B-** on the data logger

---

## Powering the Data Logger

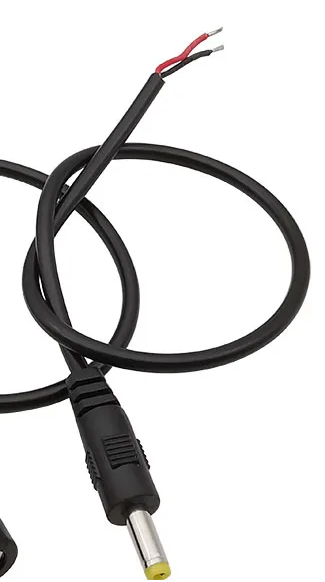
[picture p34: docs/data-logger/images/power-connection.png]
Power Connection


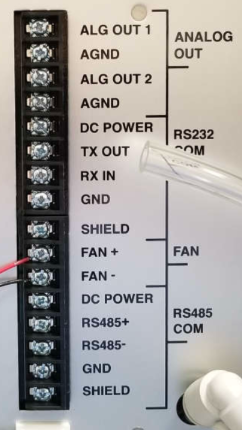
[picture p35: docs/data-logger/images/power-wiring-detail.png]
Power Wiring Detail


12V power is drawn from the BAM1022's **DC POWER** port.

| BAM1022 Expansion Interface | AirQo Data Logger Power Cable |
|---|---|
| DC POWER | Red wire (+) |
| GND | Black wire (−) |

Connect the wires to the supplied DC power barrel connector cable (paying attention to polarity), then plug into the **DC power port** on the data logger.

!!! info "Internal Battery"
    The data logger has an internal Li-ion battery that provides **backup power** in case of power interruptions from the BAM1022. It charges automatically when 12V power is connected.

!!! warning
    The data logger's internal battery does **not** provide backup power for the BAM1022 itself.

---

## Important Checks

!!! warning "Baud Rate"
    The data logger operates at a serial communication baud rate of **9600 bps** by default. This baud rate **must match** on both the data logger and the BAM1022's communication interfaces. Verify this in the BAM1022 user manual before operating.

---

## Related Pages

- [Data Logger Overview](index.md)
- [Technical Specification](technical-spec.md)
- [Data Access](data-access.md)

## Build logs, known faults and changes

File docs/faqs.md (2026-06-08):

# FAQs

Frequently asked questions about the AirQo Binos Air Monitor.

---

## General

**What does the AirQo monitor measure?**

The device measures Particulate Matter (PM2.5 and PM10), temperature, and humidity. It also tracks GPS location and battery voltage.

**How does the device connect to the internet?**

The device supports 2G GSM/GPRS, Wi-Fi, and LoRaWAN connectivity. The most common deployment uses 2G GSM with a local SIM card.

**How is the device powered?**

The device can be powered by a solar panel (5–12V input) or via USB (5V). It has an onboard rechargeable LiPo/Li-ion battery for backup power.

---

## Deployment

**How do I access my device's data?**

Log in to the [AirQo Analytics Platform](https://analytics.airqo.net), navigate to Analytics, and add your deployment location. See the [Deployment Guide](deployment.md) for the full walkthrough.

**How many sites can I monitor at once?**

You can select up to **4 sites** to view real-time data simultaneously on the dashboard.

**What height should I mount the device at?**

Mount between **2–5 metres** above ground level for representative ambient air quality readings.

---

## Maintenance

**How often should I clean the sensor?**

Clean the PM sensor inlet **monthly** using a soft brush or compressed air. Clean the solar panel surface monthly as well.

**How do I know if the battery needs replacing?**

Measure the battery voltage with a multimeter. If it reads below **3.5V** under load, replace the battery.

**The device stopped reporting data — what should I do?**

Run through the [Device Diagnosis](maintenance/diagnosis.md) checklist: check power, SIM card, GSM signal, and SD card. Connect via USB at 9600 baud to read serial diagnostic output.

---

## Firmware

**How do I update the firmware?**

See [Firmware Configuration](firmware/configuration.md) for step-by-step flashing instructions using Arduino IDE or PlatformIO.

**What firmware variants are available?**

Three variants are available:

- **AirQo Rev C** — standard production firmware (GSM/GPRS)
- **LoRaWAN v1** — for LoRaWAN network deployments
- **MQTT/ThingSpeak** — for MQTT-based integrations

---

## Related Pages

- [Deployment Guide](deployment.md)
- [Maintenance Overview](maintenance/index.md)
- [Device Diagnosis](maintenance/diagnosis.md)

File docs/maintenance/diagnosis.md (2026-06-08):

# Device Diagnosis

This page helps field engineers and technicians diagnose common faults with the AirQo Binos Air Monitor.

---

## Diagnostic Checklist

Before escalating an issue, run through the following checklist:

- [ ] Device is powered on (LED indicator active)
- [ ] Solar panel is clean and correctly oriented
- [ ] Battery voltage is above 3.5V (check with multimeter)
- [ ] SIM card is inserted and active
- [ ] GSM signal available at site (check with mobile phone)
- [ ] SD card is inserted and not full
- [ ] Sensor inlet is free of obstructions

---

## Common Issues

| Symptom | Likely Cause | Resolution |
|---|---|---|
| No power / device off | Depleted battery, faulty charging | Check solar panel orientation; measure battery voltage; replace if below 3.3V |
| No data on platform | GSM connectivity failure | Verify SIM credit/data; check signal strength; inspect antenna connection |
| Incorrect readings | Sensor contamination or failure | Clean sensor inlet; inspect PMS5003 for blockages; replace sensor if persistent |
| SD card not logging | Full card or card failure | Replace micro SD card; format as FAT32 |
| Device not transmitting | Firmware crash or config error | Connect via USB, open serial monitor at 9600 baud; reflash firmware if needed |
| RTC time drift | Backup battery depleted | Replace RTC backup battery (CR2032) |

---

## Serial Diagnostic Output

Connect the device via USB and open a serial monitor at **9600 baud** to view real-time diagnostic output:

- Sensor readings per sampling cycle
- Transmission status (success / failure)
- SD card write confirmation
- RTC timestamp

---

## Related Pages

- [Maintenance Overview](index.md)
- [Maintenance Toolkit](toolkit.md)
- [System Maintenance](system.md)
- [Firmware Configuration](../firmware/configuration.md)

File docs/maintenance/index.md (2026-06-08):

# Maintenance

The Binos Air Monitor requires routine maintenance to enhance its uptime and efficiency. Device failures or inefficiencies in a large interconnected network of monitors can have a significant impact on data quality and platform reliability.

---

## Maintenance Areas

| Area | Description |
|---|---|
| [Maintenance Toolkit](toolkit.md) | Tools and equipment needed for maintenance activities |
| [Device Diagnosis](diagnosis.md) | Diagnosing common device faults and failures |
| [System Maintenance](system.md) | Scheduled system-level maintenance procedures |

---

## Maintenance Schedule

| Frequency | Activity |
|---|---|
| **Monthly** | Visual inspection, clean sensor inlet, check mounting, clean solar panel |
| **Quarterly** | Check battery health, verify data transmission, check SD card storage |
| **As needed** | Firmware update, replace faulty sensors, battery replacement |

---

## Related Pages

- [Deployment](../deployment.md) — Initial installation guidance
- [Device Diagnosis](diagnosis.md) — Fault diagnosis guide
- [FAQs](../faqs.md) — Common questions and answers

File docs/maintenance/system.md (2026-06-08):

# System Maintenance

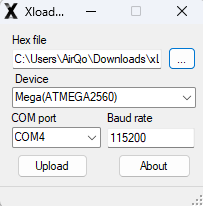
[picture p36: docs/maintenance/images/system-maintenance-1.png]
System Maintenance Overview


System maintenance covers scheduled procedures to keep the AirQo monitor network performing optimally.

---

## Scheduled Maintenance Procedures

### Monthly

1. **Visual inspection** — Check for physical damage, corrosion, loose cables or mounting hardware
2. **Sensor inlet cleaning** — Use a soft brush or compressed air to clear dust and debris from the PM sensor inlet
3. **Solar panel cleaning** — Wipe the solar panel surface with a clean, damp cloth to remove dust
4. **Mounting check** — Verify the device carrier bolts and pole mount are still securely fastened

### Quarterly

1. **Battery health check** — Measure battery voltage under load; replace if below 3.5V
2. **SD card inspection** — Check available storage; backup and format if >80% full
3. **GSM connectivity test** — Verify the device is reporting data to the platform
4. **Firmware version check** — Ensure the device is running the latest stable firmware release

### Annually

1. **Full system inspection** — Inspect all internal components for wear or corrosion
2. **Battery replacement** — Replace battery proactively even if still functional
3. **Sensor calibration check** — Compare sensor readings with a reference instrument if available

---

## Firmware Updates

When a new firmware version is released:

1. Download the latest firmware from the [repository releases](https://github.com/airqo-platform/AirQo-hardware/releases)
2. Connect the device via USB
3. Flash using Arduino IDE or PlatformIO — see [Firmware Configuration](../firmware/configuration.md)
4. Confirm device resumes normal operation after update

---

## Related Pages

- [Maintenance Overview](index.md)
- [Maintenance Toolkit](toolkit.md)
- [Device Diagnosis](diagnosis.md)

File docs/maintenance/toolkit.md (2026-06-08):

# Maintenance Toolkit

This page lists the tools and equipment required to perform maintenance on the AirQo Binos Air Monitor.

---

## Required Tools

| Tool | Purpose |
|---|---|
| Screwdriver set (Phillips & flathead) | Opening enclosure, tightening mounting hardware |
| Adjustable spanner / wrench | Mounting pole hardware |
| Multimeter | Checking battery voltage, power rails |
| Micro SD card reader | Reading/replacing SD card data logs |
| USB cable (Micro USB) | Firmware updates, serial diagnostics |
| Soft brush / compressed air | Cleaning sensor inlet and solar panel |
| Laptop with Arduino IDE / PlatformIO | Firmware flashing and diagnostics |

---

## Consumables

| Item | Notes |
|---|---|
| LiPo 3.7V 3.5AH battery | Solar-powered unit replacement battery |
| Li-ion 3.7V 8.8AH battery | Mobile unit replacement battery |
| Micro SD card (Class 10, ≤32GB) | Data logging card replacement |
| SIM card | GSM connectivity |

---

## Related Pages

- [Maintenance Overview](index.md)
- [Device Diagnosis](diagnosis.md)
- [System Maintenance](system.md)

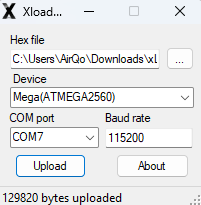
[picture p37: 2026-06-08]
docs/maintenance/images/system-maintenance-2.png

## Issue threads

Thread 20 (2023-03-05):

AT command unknown in the arduino IDE environment

settala1, 2023-03-05:
**Describe your question or issue**
A clear and concise description of the problem you're facing and what you'd like help with.
TINY_GSM_MODEM_SIM800 Library one of it's AT commands have been denied in the binary configuration environment "they say it's an undefined character. how can we go about it'
 AT+CBC, Inquire charging status and remaining battery capacity.(it's the AT command needed to be defined)
**Environment**
Arduino IDE
This information is all important; it's hard to help without a complete set of answers.

- Version of Fimrware being used: Rev C
- Version of Arduino IDE being used:Arduino 1.8.20

Baalmart, 2023-03-05:
Thanks @settala1 , I guess the rest here are better placed to assist. @deogratius2phantom @semajoel @NsubugaAnold

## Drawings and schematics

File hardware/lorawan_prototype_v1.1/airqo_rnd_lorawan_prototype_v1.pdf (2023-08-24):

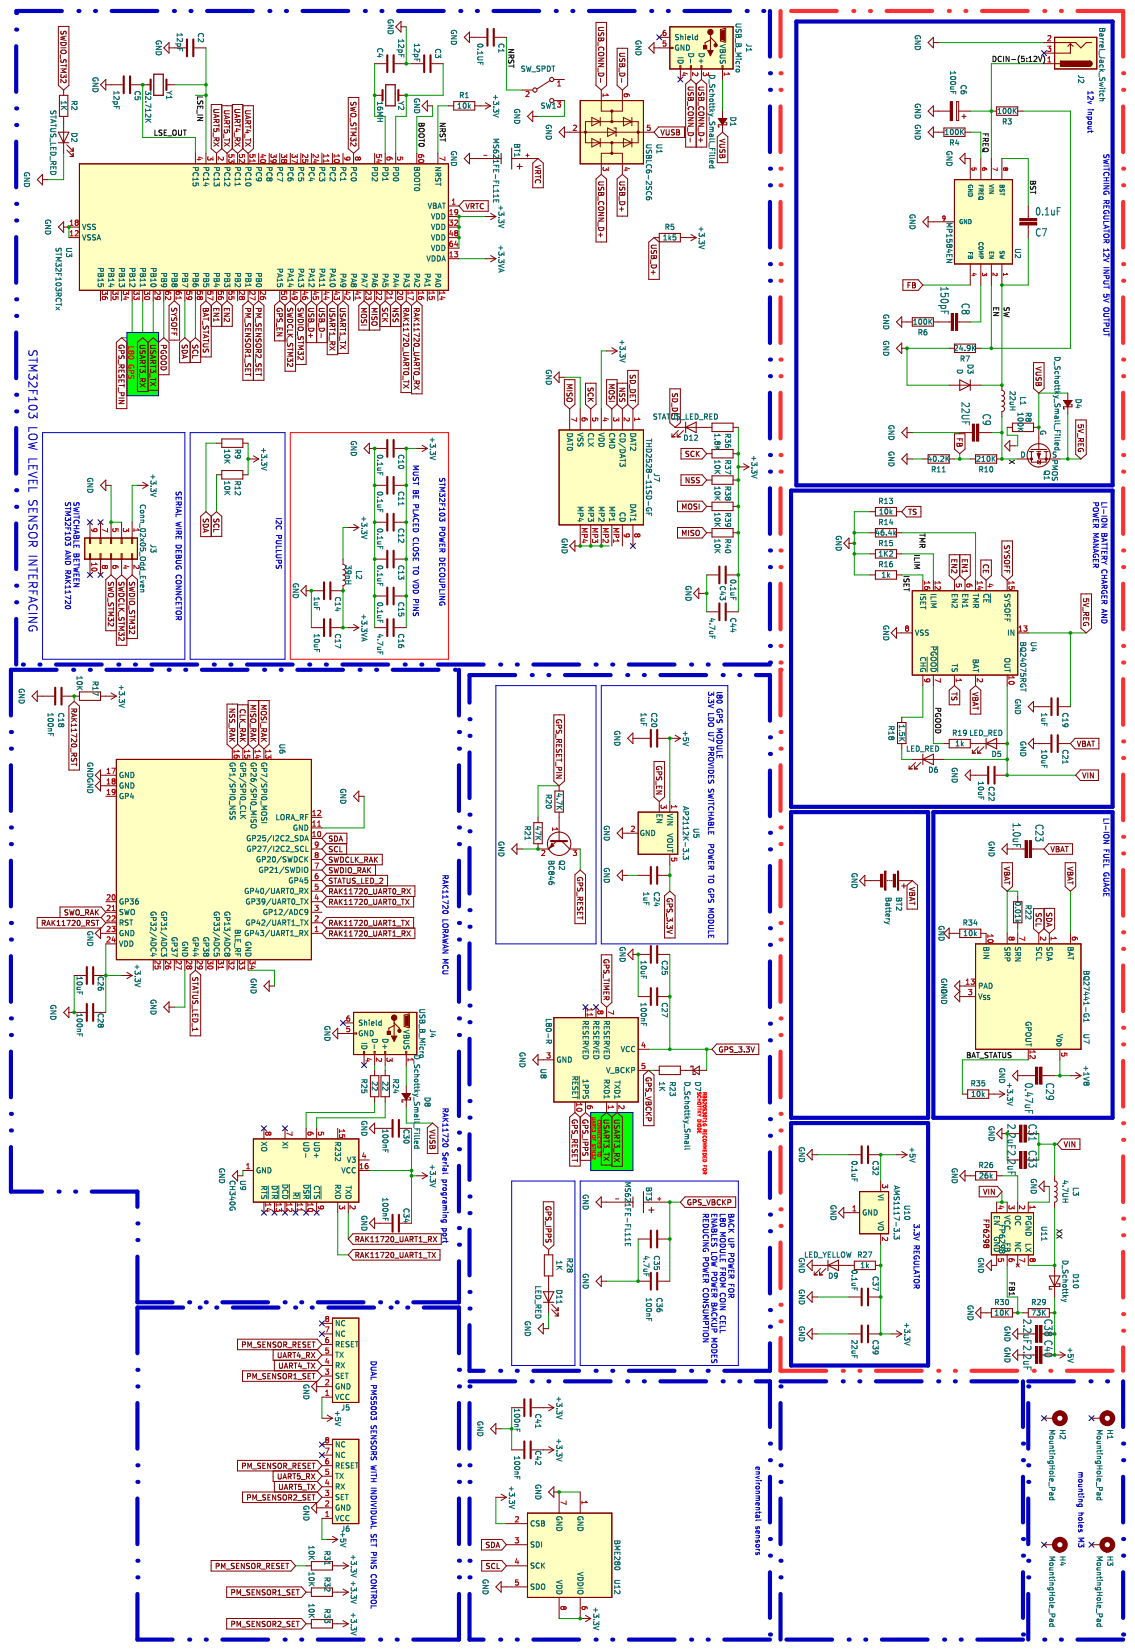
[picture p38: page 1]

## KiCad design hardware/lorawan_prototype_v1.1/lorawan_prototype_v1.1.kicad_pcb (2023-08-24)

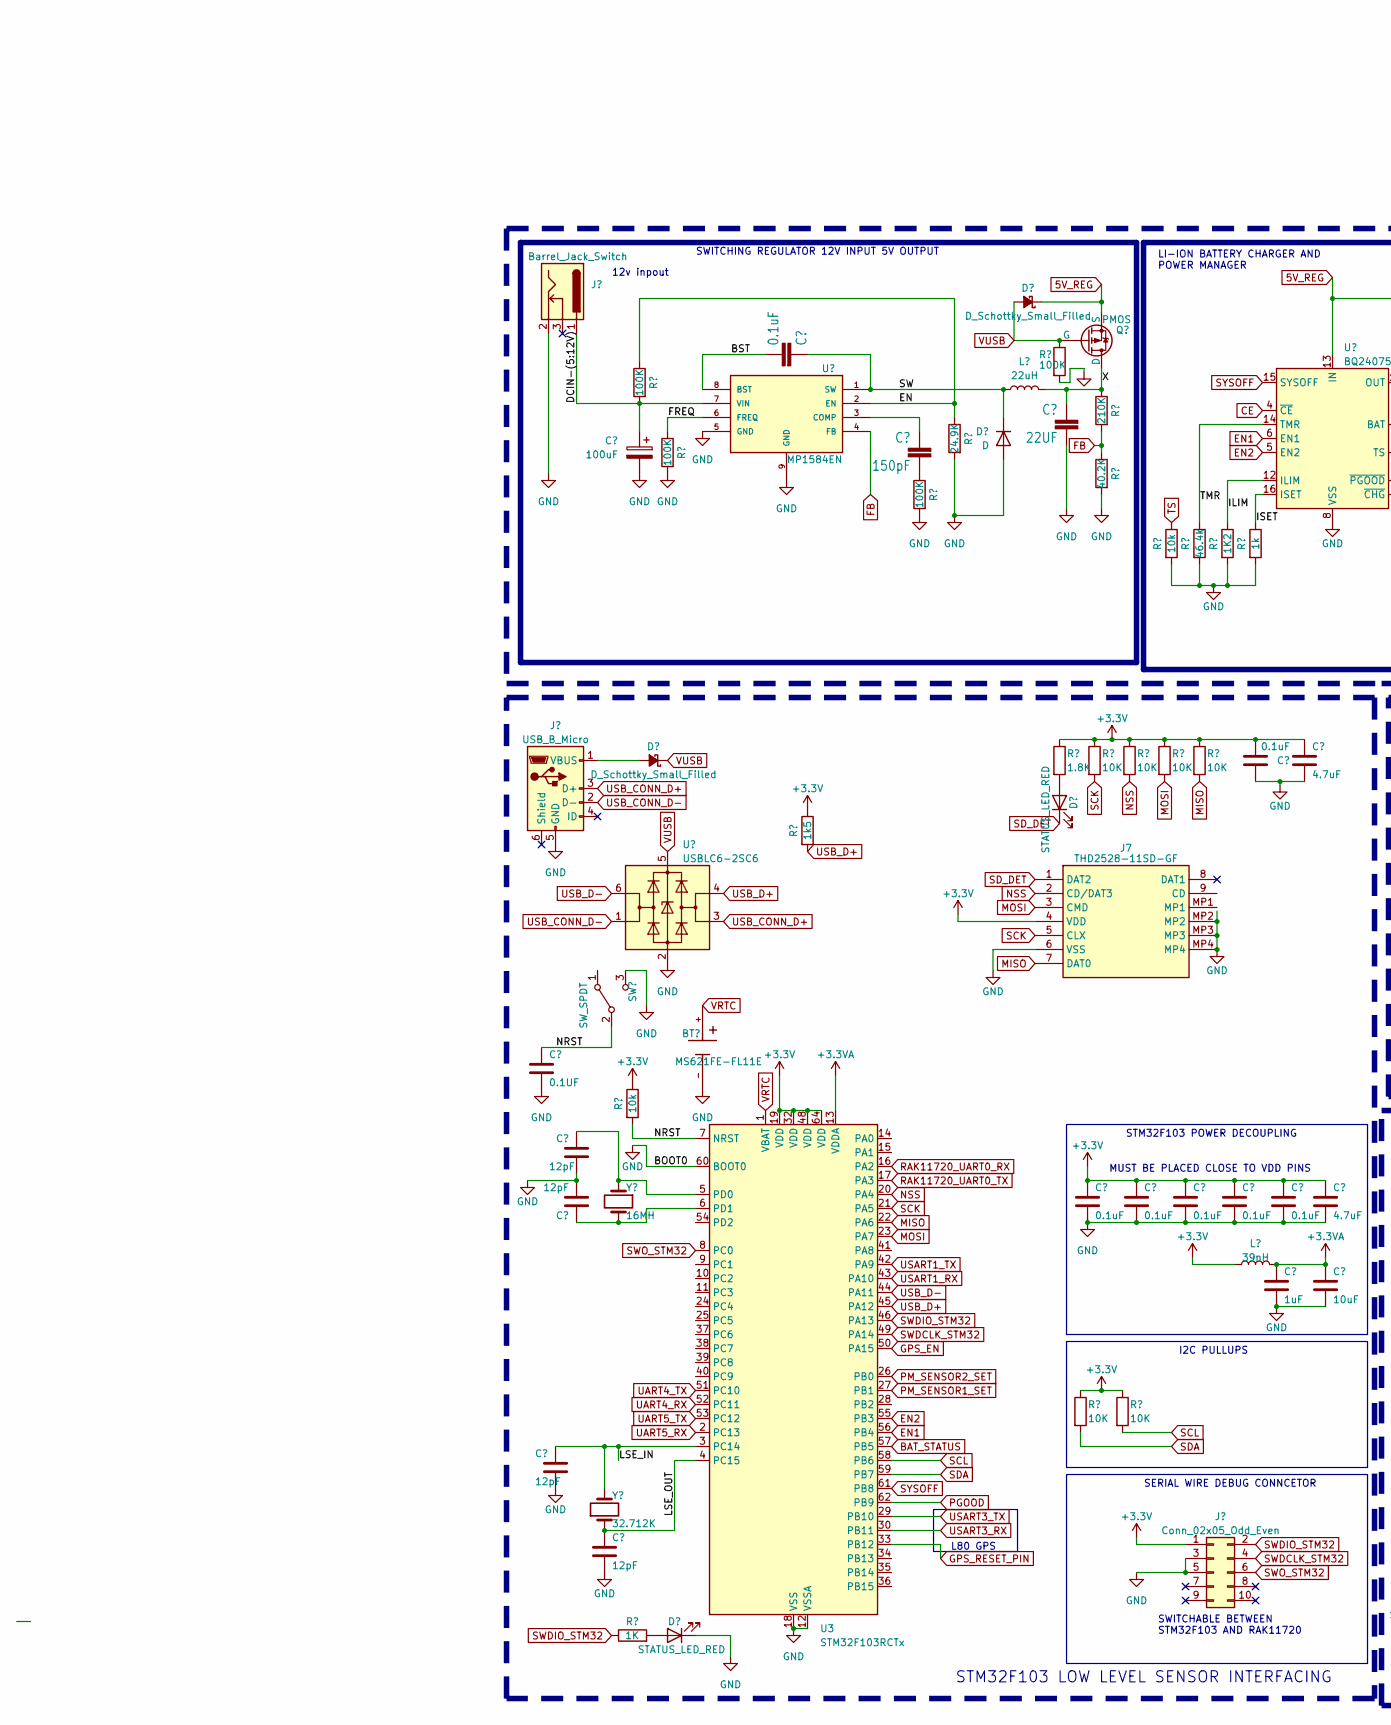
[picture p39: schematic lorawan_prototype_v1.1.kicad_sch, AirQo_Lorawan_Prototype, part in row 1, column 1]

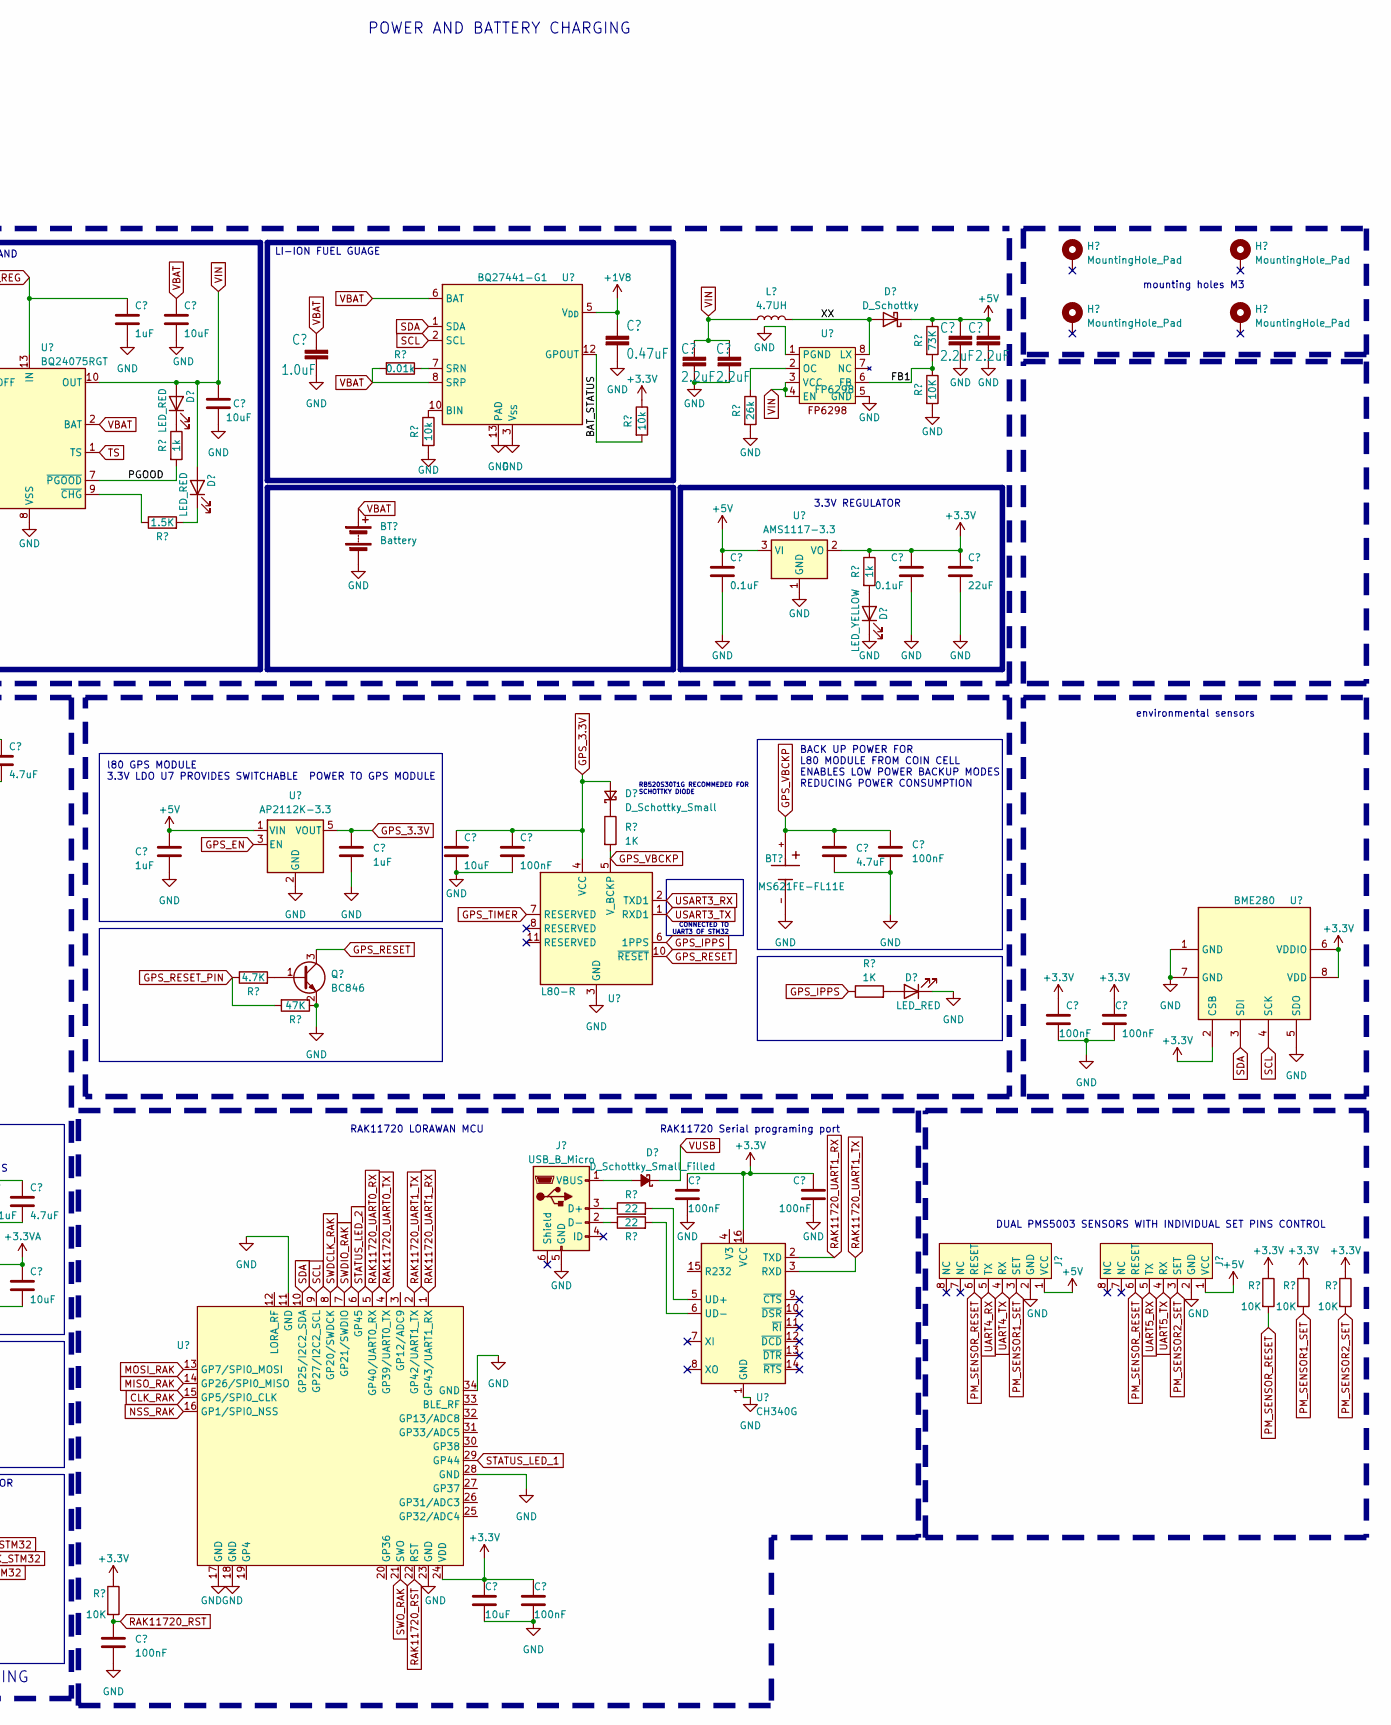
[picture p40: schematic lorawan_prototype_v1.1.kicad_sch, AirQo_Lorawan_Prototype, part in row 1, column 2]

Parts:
BT1, BT3: MS621FE-FL11E; BAT_MS621FE-FL11E; PARTREV E
BT2: Battery; BatteryHolder_Keystone_1042_1x18650
C1: 0.1UF; C_0603_1608Metric
C2, C3, C4, C5: 12pF; C_0603_1608Metric
C6: 100uF; CP_Radial_D7.5mm_P2.50mm
C7, C10, C11, C12, C13, C15, C32, C37, C43: 0.1uF; C_0603_1608Metric
C8: 150pF; C_0603_1608Metric
C9: 22UF; C_0805_2012Metric
C14, C19, C20, C24: 1uF; C_0603_1608Metric
C16, C35, C44: 4.7uF; C_0805_2012Metric
C17, C21, C22, C25, C26: 10uF; C_0805_2012Metric
C18, C27, C28, C30, C34, C36, C41, C42: 100nF; C_0603_1608Metric
C23: 1.0uF; C_0603_1608Metric
C29: 0.47uF; C_0603_1608Metric
C31, C33, C38, C40: 2.2uF; C_0603_1608Metric
C39: 22uF; C_0603_1608Metric
D1, D8: D_Schottky_Small_Filled; D_0603_1608Metric_Pad1.05x0.95mm_HandSolder
D2, D12: STATUS_LED_RED; LED_0603_1608Metric
D3: D; DIOM4336X265N
D4: D_Schottky_Small_Filled; DIOM4336X265N
D5, D6, D11: LED_RED; LED_0603_1608Metric
D7: D_Schottky_Small; D_1206_3216Metric
D9: LED_YELLOW; LED_0603_1608Metric
D10: D_Schottky; DIOM4336X265N
H1, H2, H3, H4: MountingHole_Pad; MountingHole_3mm_Pad_Via
J1, J4: USB_B_Micro; USB_Micro-B_GCT_USB3076-30-A
J2: Barrel_Jack_Switch; BarrelJack_CUI_PJ-063AH_Horizontal
J3: Conn_02x05_Odd_Even; IDC-Header_2x05_P2.54mm_Vertical
J5, J6: Molex_CLIK-Mate_502382-0870_1x08-1MP_P1.25mm_Vertical
J7: THD2528-11SD-GF; THD252811SDGF; Manufacturer_Part_Number THD2528-11SD-GF
L1: 22uH; L_7.3x7.3_H4.5
L2: 39nH; L_0603_1608Metric
L3: 4.7UH; L_7.3x7.3_H4.5
Q1: PMOS; TO-252-2
Q2: BC846; SOT-23
R1: 10k; R_0603_1608Metric_Pad0.98x0.95mm_HandSolder
R2, R23, R28: 1K; R_0603_1608Metric
R3, R4, R6, R8: 100K; R_0603_1608Metric
R5: 1k5; R_0603_1608Metric_Pad0.98x0.95mm_HandSolder
R7: 24.9K; R_0603_1608Metric
R9, R12, R17, R30, R31, R32, R33, R37, R38, R39, R40: 10K; R_0603_1608Metric
R10: 210K; R_0603_1608Metric
R11: 40.2K; R_0603_1608Metric
R13, R34, R35: 10k; R_0603_1608Metric
R14: 46.4k; R_0603_1608Metric
R15: 1K2; R_0603_1608Metric
R16, R19, R27: 1k; R_0603_1608Metric
R18: 1.5K; R_0603_1608Metric
R20: 4.7K; R_0603_1608Metric
R21: 47K; R_0603_1608Metric
R22: 0.01k; R_0603_1608Metric
R24, R25: 22; R_0603_1608Metric_Pad0.98x0.95mm_HandSolder
R26: 26k; R_0603_1608Metric
R29: 73K; R_0603_1608Metric
R36: 1.8K; R_0603_1608Metric
SW1: SW_SPDT; SW_SPST_PTS645
U1: USBLC6-2SC6; SOT-23-6
U2: MP1584EN; SOIC127P600X170-9N
U3: STM32F103RCTx; LQFP-64_10x10mm_P0.5mm
U4: BQ24075RGT; VQFN-16-1EP_3x3mm_P0.5mm_EP1.6x1.6mm
U5: AP2112K-3.3; SOT-23-5
U6: RAK3172
U7: BQ27441-G1; Texas_S-PDSO-N12
U8: L80-R; Quectel_L80-R
U9: CH340G; SOIC-16_3.9x9.9mm_P1.27mm
U10: AMS1117-3.3; SOT-223-3_TabPin2
U11: FP6298; SOIC127P599X175-9N
U12: BME280; Bosch_LGA-8_2.5x2.5mm_P0.65mm_ClockwisePinNumbering
Y1: 32.712K; Crystal_C38-LF_D3.0mm_L8.0mm_Horizontal
Y2: 16MH; Crystal_HC52-6mm_Vertical

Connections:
5V_REG: C19.1, D4.1 (K), Q1.3 (S), U4.13 (IN)
+1V8: C29.1, U7.5 (V_{DD})
+3.3V: C10.1, C11.1, C12.1, C13.1, C15.1, C16.1, C26.1, C28.1, C30.1, C34.1, C37.1, C39.1, C41.1, C42.1, C43.2, C44.1, J3.1, J7.4 (VDD), L2.1, R1.1, R5.1, R9.1, R12.1, R17.1, R27.1, R31.1, R32.1, R33.1, R35.1, R36.1, R37.1, R38.1, R39.1, R40.1, U3.19 (VDD), U3.32 (VDD), U3.48 (VDD), U3.64 (VDD), U6.24 (VDD), U9.16 (VCC), U10.2 (VO), U12.2 (CSB), U12.6 (VDDIO), U12.8 (VDD)
+3.3VA: C14.1, C17.1, L2.2, U3.13 (VDDA)
+5V: C20.1, C32.1, C38.1, C40.1, D10.1 (K), J5.1 (VCC), J6.1 (VCC), R29.1, U5.1 (VIN), U10.3 (VI)
/BST: C7.2, U2.8 (BST)
/DCIN-(5:12V): C6.1, J2.1, R3.2, U2.7 (VIN)
/EN: R3.1, R7.1, U2.2 (EN)
/FB1: R29.2, R30.1, U11.6 (FB)
/FREQ: R4.1, U2.6 (FREQ)
/ILIM: R15.1, U4.12 (ILIM)
/ISET: R16.1, U4.16 (ISET)
/LSE_IN: C2.1, U3.3 (PC14), Y1.2
/LSE_OUT: C5.1, U3.4 (PC15), Y1.1
/NRST: C1.1, R1.2, SW1.2 (B), U3.7 (NRST)
/SW: C7.1, D3.1 (K), L1.2, U2.1 (SW)
/TMR: R14.1, U4.14 (TMR)
/X: C9.1, L1.1, Q1.1 (D), R10.1
/XX: D10.2 (A), L3.2, U11.8 (LX)
BAT_STATUS: R35.2, U3.57 (PB5), U7.12 (GPOUT)
CE: U4.4 (~CE)
CLK_RAK: U6.15 (GP5/SPI0_CLK)
EN1: U3.56 (PB4), U4.6 (EN1)
EN2: U3.55 (PB3), U4.5 (EN2)
FB: R10.2, R11.1, U2.4 (FB)
GND: BT1.-, BT2.2 (-), BT3.-, C1.2, C2.2, C3.2, C4.2, C5.2, C6.2, C9.2, C10.2, C11.2, C12.2, C13.2, C14.2, C15.2, C16.2, C17.2, C18.2, C19.2, C20.2, C21.2, C22.2, C23.2, C24.2, C25.2, C26.2, C27.2, C28.2, C29.2, C30.2, C31.2, C32.2, C33.2, C34.2, C35.2, C36.1, C37.2, C38.2, C39.2, C40.2, C41.2, C42.2, C43.1, C44.2, D2.1 (K), D3.2 (A), D9.1 (K), D11.1 (K), J1.5 (GND), J2.2, J3.3, J3.5, J4.5 (GND), J5.2 (GND), J6.2 (GND), J7.6 (VSS), J7.MP2, J7.MP3, J7.MP4, Q2.2 (E), R4.2, R6.2, R7.2, R8.2, R11.2, R13.2, R14.2, R15.2, R16.2, R21.1, R26.2, R30.2, R34.2, SW1.3 (C), U1.2 (GND), U2.5 (GND), U2.9 (GND), U3.12 (VSSA), U3.18 (VSS), U3.31 (VSS), U3.47 (VSS), U3.60 (BOOT0), U3.63 (VSS), U4.8 (VSS), U4.17 (VSS), U5.2 (GND), U6.11 (GND), U6.17 (GND), U6.18 (GND), U6.23 (GND), U6.28 (GND), U6.34 (GND), U7.3 (V_{SS}), U7.13 (PAD), U8.3 (GND), U8.12 (GND), U9.1 (GND), U10.1 (GND), U11.1 (PGND), U11.5 (GND), U12.1 (GND), U12.5 (SDO), U12.7 (GND)
GPS_3.3V: C24.1, C25.1, C27.1, D7.2 (A), U5.5 (VOUT), U8.4 (VCC)
GPS_EN: U3.50 (PA15), U5.3 (EN)
GPS_IPPS: R28.1, U8.6 (1PPS)
GPS_RESET: Q2.3 (C), U8.10 (~RESET)
GPS_RESET_PIN: R20.1, R21.2, U3.33 (PB12)
GPS_TIMER: U8.7 (RESERVED)
GPS_VBCKP: BT3.+, C35.1, C36.2, R23.2, U8.5 (V_BCKP)
MISO: J7.7 (DAT0), R40.2, U3.22 (PA6)
MISO_RAK: U6.14 (GP26/SPI0_MISO)
MOSI: J7.3 (CMD), R39.2, U3.23 (PA7)
MOSI_RAK: U6.13 (GP7/SPI0_MOSI)
NSS: J7.2 (CD/DAT3), R38.2, U3.20 (PA4)
NSS_RAK: U6.16 (GP1/SPI0_NSS)
unnamed: C8.2, R6.1
unnamed: D1.2 (A), J1.1 (VBUS)
unnamed: D2.2 (A), R2.2
unnamed: D5.1 (K), R19.1
unnamed: D6.1 (K), R18.2
unnamed: D7.1 (K), R23.1
unnamed: D8.2 (A), J4.1 (VBUS)
unnamed: D9.2 (A), R27.2
unnamed: D11.2 (A), R28.2
unnamed: D12.2 (A), R36.2
unnamed: J4.3 (D+), R24.1
unnamed: J4.2 (D-), R25.1
unnamed: Q2.1 (B), R20.2
unnamed: C8.1, U2.3 (COMP)
unnamed: C3.1, U3.5 (PD0), Y2.1
unnamed: C4.1, U3.6 (PD1), Y2.2
unnamed: R18.1, U4.9 (~CHG)
unnamed: R34.1, U7.10 (BIN)
unnamed: R22.1, U7.7 (SRN)
unnamed: R24.2, U9.5 (UD+)
unnamed: R25.2, U9.6 (UD-)
unnamed: R26.1, U11.2 (OC)
PGOOD: R19.2, U3.62 (PB9), U4.7 (~PGOOD)
PM_SENSOR1_SET: J5.3 (SET), R32.2, U3.27 (PB1)
PM_SENSOR2_SET: J6.3 (SET), R33.2, U3.26 (PB0)
PM_SENSOR_RESET: J5.6 (RESET), J6.6 (RESET), R31.2
RAK11720_RST: C18.1, R17.2, U6.22 (RST)
RAK11720_UART0_RX: U3.16 (PA2), U6.5 (GP40/UART0_RX)
RAK11720_UART0_TX: U3.17 (PA3), U6.4 (GP39/UART0_TX)
RAK11720_UART1_RX: U6.1 (GP43/UART1_RX), U9.2 (TXD)
RAK11720_UART1_TX: U6.2 (GP42/UART1_TX), U9.3 (RXD)
SCK: J7.5 (CLX), R37.2, U3.21 (PA5)
SCL: R12.2, U3.58 (PB6), U6.9 (GP27/I2C2_SCL), U7.2 (SCL), U12.4 (SCK)
SDA: R9.2, U3.59 (PB7), U6.10 (GP25/I2C2_SDA), U7.1 (SDA), U12.3 (SDI)
SD_DET: D12.1 (K), J7.1 (DAT2)
STATUS_LED_1: U6.29 (GP44)
STATUS_LED_2: U6.6 (GP45)
SWDCLK_RAK: U6.8 (GP20/SWDCK)
SWDCLK_STM32: J3.4, U3.49 (PA14)
SWDIO_RAK: U6.7 (GP21/SWDIO)
SWDIO_STM32: J3.2, R2.1, U3.46 (PA13)
SWO_RAK: U6.21 (SWO)
SWO_STM32: J3.6, U3.8 (PC0)
SYSOFF: U3.61 (PB8), U4.15 (SYSOFF)
TS: R13.1, U4.1 (TS)
UART4_RX: J5.5 (TX), U3.52 (PC11)
UART4_TX: J5.4 (RX), U3.51 (PC10)
UART5_RX: J6.5 (TX), U3.2 (PC13)
UART5_TX: J6.4 (RX), U3.53 (PC12)
USART1_RX: U3.43 (PA10)
USART1_TX: U3.42 (PA9)
USART3_RX: U3.30 (PB11), U8.2 (TXD1)
USART3_TX: U3.29 (PB10), U8.1 (RXD1)
USB_CONN_D+: J1.3 (D+), U1.3 (I/O2)
USB_CONN_D-: J1.2 (D-), U1.1 (I/O1)
USB_D+: R5.2, U1.4 (I/O2), U3.45 (PA12)
USB_D-: U1.6 (I/O1), U3.44 (PA11)
VBAT: BT2.1 (+), C21.1, C23.1, R22.2, U4.2 (BAT), U4.3 (BAT), U7.6 (BAT), U7.8 (SRP)
VIN: C22.1, C31.1, C33.1, D5.2 (A), D6.2 (A), L3.1, U4.10 (OUT), U4.11 (OUT), U11.3 (VCC), U11.4 (EN)
VRTC: BT1.+, U3.1 (VBAT)
VUSB: D1.1 (K), D4.2 (A), D8.1 (K), Q1.2 (G), R8.1, U1.5 (VBUS)

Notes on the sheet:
SWITCHABLE BETWEEN STM32F103 AND RAK11720
LI-ION BATTERY CHARGER AND POWER MANAGER
BACK UP POWER FOR L80 MODULE FROM COIN CELL ENABLES LOW POWER BACKUP MODES REDUCING POWER CONSUMPTION
STM32F103 LOW LEVEL SENSOR INTERFACING
mounting holes M3
RB520S30T1G RECOMMEDED FOR SCHOTTKY DIODE
SERIAL WIRE DEBUG CONNCETOR
CONNECTED TO UART3 OF STM32
l80 GPS MODULE 3.3V LDO U7 PROVIDES SWITCHABLE POWER TO GPS MODULE
RAK11720 LORAWAN MCU
LI-ION FUEL GUAGE
POWER AND BATTERY CHARGING
12v inpout
3.3V REGULATOR
I2C PULLUPS
DUAL PMS5003 SENSORS WITH INDIVIDUAL SET PINS CONTROL
MUST BE PLACED CLOSE TO VDD PINS
SWITCHING REGULATOR 12V INPUT 5V OUTPUT
L80 GPS
STM32F103 POWER DECOUPLING
RAK11720 Serial programing port
environmental sensors

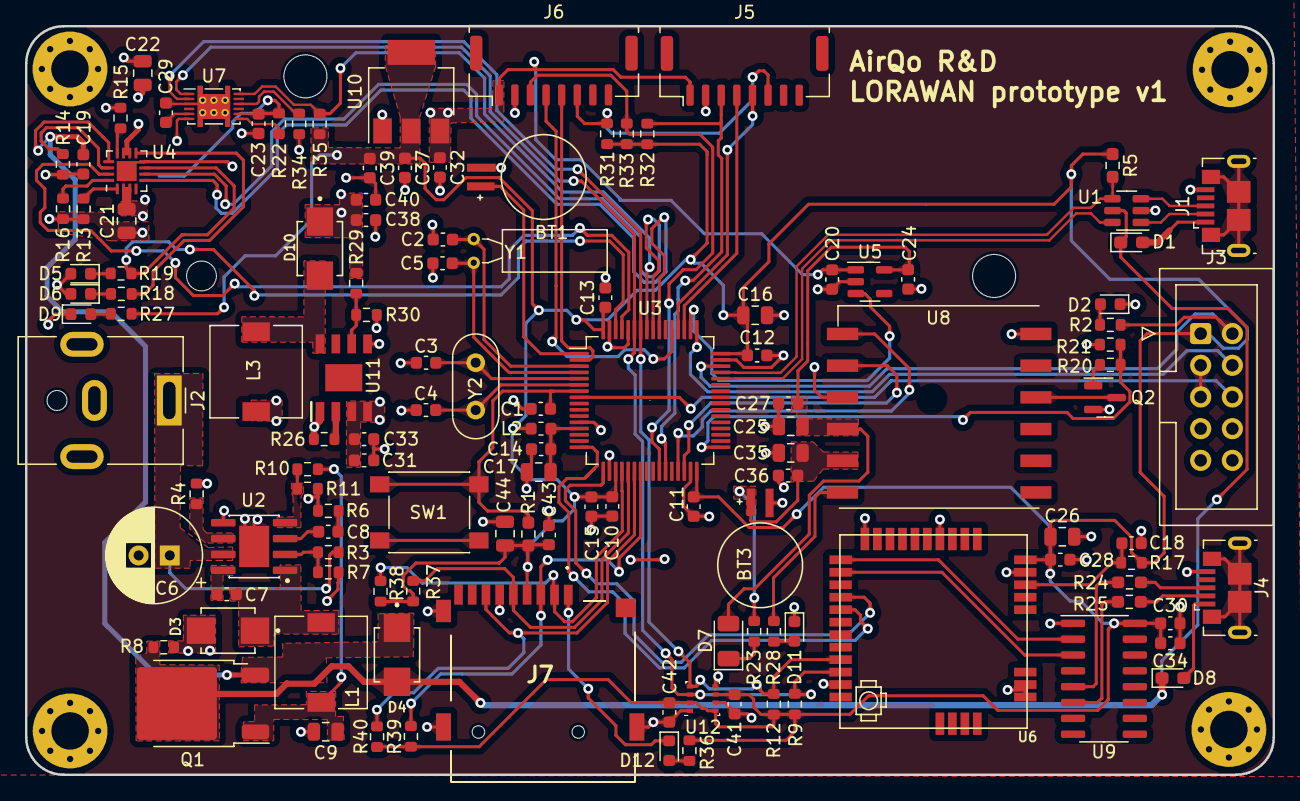
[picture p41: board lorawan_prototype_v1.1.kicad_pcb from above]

Board: 2 copper layers, 100.0 x 60.0 mm, 130 parts (1 on the bottom side), 87 nets.

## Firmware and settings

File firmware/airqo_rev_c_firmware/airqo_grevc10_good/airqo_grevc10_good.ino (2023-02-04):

//************************************************************************************************





// Select your modem:
//#define TINY_GSM_MODEM_SIM7600
#define TINY_GSM_MODEM_SIM800

#if !defined(TINY_GSM_RX_BUFFER)
#define TINY_GSM_RX_BUFFER 1024
#endif

// See all AT commands, if wanted
// #define DUMP_AT_COMMANDS

// Define the serial console for debug prints, if needed
#define TINY_GSM_DEBUG Serial

// Range to attempt to autobaud
// NOTE:  DO NOT AUTOBAUD in production code.  Once you've established
// communication, set a fixed baud rate using modem.setBaud(#).
#define GSM_AUTOBAUD_MIN 4800
#define GSM_AUTOBAUD_MAX 115200

// Add a reception delay, if needed.
// This may be needed for a fast processor at a slow baud rate.
// #define TINY_GSM_YIELD() { delay(2); }





#define GSM_PIN ""

// Your GPRS credentials, if any
const char apn[]      = "TM"; //internet
const char gprsUser[] = "";
const char gprsPass[] = "";


#define TINY_GSM_TEST_GPRS true
#define TINY_GSM_TEST_TEMPERATURE true
#define TINY_GSM_TEST_GSM_LOCATION true
#define TINY_GSM_TEST_NTP true
#define TINY_GSM_TEST_TIME true


// set GSM PIN, if any


#include <TinyGsmClient.h>
#include <ArduinoHttpClient.h>

#ifdef DUMP_AT_COMMANDS
#include <StreamDebugger.h>
StreamDebugger debugger(Serial1, Serial);
TinyGsm        modem(debugger);
#else
TinyGsm        modem(Serial1);
#endif

//#ifdef USE_SSL
//TinyGsmClientSecure client(modem);
//const int           port = 443;
//#else
//TinyGsmClient  client(modem);
//const int      port = 80;
//#endif


//const int           sPort = 443;
const int      port = 80;



//****************************MQTT*****************************************************************
//const char* broker = "broker.mqttdashboard.com";
////const char* broker = "395123438a454425b8bfbdba25d4fa11.s1.eu.hivemq.cloud";
//const char* AirqoPubTopic="AirQo/Pub";
//const char* AirqoSubTopic="AirQo/Sub";
//uint32_t lastReconnectAttempt = 0;
//
//
//boolean runOnce = false;
//
//#include<PubSubClient.h>
//PubSubClient   mqtt(client);



//*********************************LOW POWER ****************************************************************
#include <SPI.h>
#include "LowPower.h"
#include <Wire.h>

///*****************SD card and RTC and Json ******************************************************************
//#include <pgmspace.h>
#include <SD.h>
#include "RTClib.h"

RTC_DS3231 rtc;
int8_t SDCS = "58";
#define sdcardChipSelect SDCS



int jsonEnd=0;
File dataFile;

boolean jsonStart = true;
boolean SDFileStart = true;
boolean SDInserted = false;
boolean RTCAvailable = false;
boolean SDFileReadable= false;

char*  fileName = "tempData.txt";
//String SDTemp = "tempData.txt";
char jsonBuffer [1300]; // Initialize the jsonBuffer to hold data

//char buff[500];  // Initialize the jsonBuffer to hold SD data


//int8_t count = 10;
int8_t countCon;
int8_t countConMax = 5; // STORAGE COUNT MAX HOW MANY ENTRIES STORED
int8_t bulkMax = 5;  // HOW MANY ENTRIES ARE MADE FOR BULK STRINGED UPLOAD. SRAM CAPACITY TO BE MINDED
int8_t countConMaxDeltat = 5; // STORAGE COUNT MAX DeltaT

long startMillis; long millsCTR = 0; 
//char dateTime[26];



//****************** FOTA PARAMS ******************************************************************************
#include <EEPROM.h>
#include <avr/wdt.h>


float fetchedFirmawareVersion = 0.0;
boolean fetchedUpdateCtrl = false;
String fetchedConfigFileToken = "";
String fetchedFirmawareFileToken = "";
long controlChannelID = 1694247;
String controlChannelReadKey = "23BLMB7RX4E3KUZB";
int8_t NoConfigLine;


int8_t DOWNLOAD_FAILED = 0;
int8_t DOWNLOAD_COMPLETE = 1;
int8_t DOWNLOAD_INCOMPLETE = 2;

long FOTATimer = 0; long FOTAInterval = 10800000; boolean FOTACTR = false; ///3hours check interval


///****************Location and time variables****************************************************
/// GSM/ internet time variables
  int   year3    = 0;
  int   month3   = 0;
  int   day3     = 0;
  int   hour3    = 0;
  int   min3     = 0;
  int   sec3     = 0;
  float timezone = 0;


  /// GPS time variables
  float lat2      = 0;  float lon2     = 0;  float speed2    = 0;  float alt2      = 0;  int   vsat2     = 0;  int   usat2     = 0;  float accuracy2 = 0;  
  
  int   year2     = 0;  int   month2    = 0;  int   day2      = 0;  int   hour2     = 0;  int   min2      = 0;  int   sec2      = 0;

 char daysOfTheWeek[7][12] = {"Sunday", "Monday", "Tuesday", "Wednesday", "Thursday", "Friday", "Saturday"};


///**********************************PMS5003 delacrations********************
#include "PMS.h"
#include <SoftwareSerial.h>
SoftwareSerial mySerial(13, 12); // RX, TX

#define pmsSwitch A2
PMS pms(Serial3);PMS::DATA data;
PMS pms2(mySerial);PMS::DATA data2;

//***********************************DHT11, BME, SHT25 declarations**************************************************************** 
#include "uFire_SHT20.h"
uFire_SHT20 sht20;
int8_t SHTIntTemp; int8_t SHTIntHumidity;

#include <dht11.h>
dht11 DHT11;
int8_t IntTemp; int8_t IntHumidity;
int8_t csq;
int8_t temp;

#include <Adafruit_Sensor.h>
#include <Adafruit_BME280.h>

Adafruit_BME280 bme;
#define DHT11PIN A3
#define IandETempSwitch A8

float ExtTemp; float ExtHumidity; float ExtPressure; int ExtAltitude;



//************************************DEV props***************************************************************
boolean EnableAlarms;
boolean DebugEnable;


boolean DeploymentMode;
#define StaticDeploymentMode  0
#define MobileDeploymentMode  1
String deploymentDescription;

int8_t MobileOperator;
#define MTN  0
#define Airtel  1
#define General  2

//String DevRevDisplayValue[]={"Rev A","Rev B","Rev C"};
//int8_t DevRev;
//#define RevA  0
//#define RevB  1
//#define RevC  2

float FirmwareVersion = 2.0;
String FirwareVersionDisplay;
String DevName;
String DevGen;
int8_t GsmDEF;



String MobileOperatorDisplayValue[]={"MTN", "Airtel", "All"};


#define MAX_SLEEP_ITERATIONS   50
#define CommsSwitch A0
#define Battery A1
#define GSMReset 10 



int8_t pmSamples; 
int8_t start = 0; 
int8_t sleepCounter = 0; //int waitTime = 10000;
boolean started=false;
//*************************************************************************************************** 


//************************* Define the thingspeak information *****************************

int numdata;
//char inSerial[50];
int i = 0;

char datastreamId[] = "1";
bool GPSworks = false;
int8_t failtimes = 0;

long channelId; //=  1205188;
char server[] = "api.thingspeak.com"; // ThingSpeak Server
char thingSpeakAddress[] = "184.106.153.149";
char writeAPIKey[30]; // = "3D65XPOPLCI1IW20";

char toPostGPSData[100];    


//****************** EEPROM CONFIG *************************************************
#include <EEPROM.h>
String readString;

#define configTrigger 2 

//****************** Device properties.**********************************************
  void DevProperties(){
 
 
  //delay(1000);
  
 // DeploymentMode = StaticDeploymentMode;
  EnableAlarms = true;
  DebugEnable = true;

  //DebugEnable = false;
  //MobileOperator = Airtel;
  //MobileOperator = MTN;
    MobileOperator = General;

 //DevRev = RevC;
 // DevName = "AQG5"+DevNumber+""+ DevRevDisplayValue[DevRev];
 // DevName = read_String(1)+" "+ DevRevDisplayValue[DevRev];  FirmwareVersion
  DevName = read_String(1);
  FirwareVersionDisplay = "Firmware Version: "+ String(FirmwareVersion); 
  channelId = read_EE(31).toInt();
  
  //writeAPIKey = read_String(61); 
  readtobuffer(61, writeAPIKey);  writeAPIKey[strlen(writeAPIKey)-1] = '\0';
  DeploymentMode =  read_EE(100).toInt();
  SDCS = read_EE(103).toInt();
  if(SDCS =="" ||SDCS == "0"){ SDCS = 58;}
//  GsmDEF = read_String(108).toInt();
//
//  
//  
//  if(GsmDEF == 0 ){
//    Serial.println("haz");
//    #define TINY_GSM_MODEM_SIM800
//    }
//    else if(GsmDEF ==1 ){
//      Serial.println("hazel");
//      #define TINY_GSM_MODEM_SIM7600
//     }
//   else{
//    Serial.println("hazel joel");
//    #define TINY_GSM_MODEM_SIM7600
//   }

   
  if(DebugEnable){
  Serial.println(F(""));
  Serial.println(DevName);
  Serial.println(FirwareVersionDisplay);
  Serial.println("Mobile Operator: "+MobileOperatorDisplayValue[MobileOperator]);
  }
  //DeploymentMode = MobileDeploymentMode;
  if(DeploymentMode == StaticDeploymentMode){
    deploymentDescription = "Static Deployment"; 
    pmSamples = 5;    
        }else{
      deploymentDescription = "Mobile Deployment";
      pmSamples = 10;
      }if(DebugEnable){
      Serial.println(deploymentDescription);
      Serial.println("SD CS: "+String(SDCS));}
       if(EnableAlarms){
  noTone(22);  tone(22, 4000, 200); }
  }





void startGsm(uint8_t gsmSwitch)
{
    Serial.println(F("starting gsm now"));
    digitalWrite(gsmSwitch,HIGH);
   // Serial1.begin(9600);
    modem.init();
    Serial.println(modem.getModemInfo());
    modem.waitForNetwork(20000L,true);
    if(modem.isNetworkConnected())
    {
        //Serial.println(getGsmTimeStamp());
        Serial.print(F("connected to:"));
        Serial.println(modem.getOperator());
        //getGsmTimeStamp();
        Serial.println(modem.getSignalQuality());
        //Serial.println(checkBalances());
        modem.gprsConnect(apn);
        if(modem.isGprsConnected())
        {
            
            Serial.print(F("connected to:"));Serial.println(apn);
        }
    }
}
  

  void modemInfo(){
  digitalWrite(CommsSwitch, HIGH);
   if(DebugEnable){Serial.print(F("Starting"));
   Serial.print(F(" * ")); delay(1000);   Serial.print(F(" * "));delay(1000);   Serial.print(F(" * "));delay(1000);
   Serial.print(F(" * "));delay(1000);   Serial.print(F(" * "));delay(1000);   Serial.print(F(" * "));delay(1000);
   Serial.print(F(" * "));delay(1000);   Serial.print(F(" * "));delay(1000);   Serial.print(F(" * "));delay(1000);
   Serial.print(F(" * "));delay(1000);   Serial.print(F(" * "));delay(1000);   Serial.print(F(" * "));delay(1000);
   Serial.print(F(" * "));delay(1000);   Serial.print(F(" * "));delay(1000);   Serial.print(F(" * "));delay(1000);
   Serial.print(F(" * "));delay(1000);   Serial.print(F(" * "));Serial.println(F(""));}
   
  
     // Restart takes quite some time
  // To skip it, call init() instead of restart()  SerialDBG("Initializing modem...");
  //if (!modem.restart()) {
   if (!modem.init()) {
    if(DebugEnable){Serial.println(F("Failed to restart modem, delaying 10s and retrying"));}
    // restart autobaud in case GSM just rebooted
    // TinyGsmAutoBaud(SerialAT, GSM_AUTOBAUD_MIN, GSM_AUTOBAUD_MAX);
    return;
  }

  String name = modem.getModemName();
  DBG("Modem Name:", name);

  String modemInfo = modem.getModemInfo();
  DBG("Modem Info:", modemInfo);



  if(DebugEnable){Serial.println(F("Waiting for network..."));}
  if (!modem.waitForNetwork(600000L, true)) {
    delay(10000);
    return;
  }

  if (modem.isNetworkConnected()) {  if(DebugEnable){Serial.println(F("Network connected"));} }
 // modem.gprsConnectImpl();

#if TINY_GSM_TEST_GPRS
  DBG("Connecting to", apn);
  if (!modem.gprsConnect(apn, gprsUser, gprsPass)) {
     delay(10000);
    return;
  }

  bool res = modem.isGprsConnected();
  DBG("GPRS status:", res ? "connected" : "not connected");

  String ccid = modem.getSimCCID();
  DBG("CCID:", ccid);

  String imei = modem.getIMEI();
  DBG("IMEI:", imei);

  String imsi = modem.getIMSI();
  DBG("IMSI:", imsi);

  String cop = modem.getOperator();
  DBG("Operator:", cop);

  IPAddress local = modem.localIP();
  DBG("Local IP:", local);

  csq = modem.getSignalQuality();
  DBG("Signal quality:", csq);
#endif


#if TINY_GSM_TEST_NTP && defined TINY_GSM_MODEM_HAS_NTP
  if(DebugEnable){Serial.println(F("Asking modem to sync with NTP"));}
  modem.NTPServerSync("132.163.96.5", 20);
#endif

#if TINY_GSM_TEST_TIME && defined TINY_GSM_MODEM_HAS_TIME

  for (int8_t i = 3; i; i--) {
    if(DebugEnable){Serial.println(F("Requesting current network time"));}
    if (modem.getNetworkTime(&year3, &month3, &day3, &hour3, &min3, &sec3,
                             &timezone)) {
      DBG("Year:", year3, "\tMonth:", month3, "\tDay:", day3);
      DBG("Hour:", hour3, "\tMinute:", min3, "\tSecond:", sec3);
      DBG("Timezone:", timezone);
      //delay(100);
      if(DebugEnable){Serial.println(F("Adjusting RTC"));}
     delay(50);
      rtc.adjust(DateTime(year3, month3, day3, hour3, min3, sec3));
       //rtc.adjust(DateTime(F(__DATE__), F(__TIME__)));
       
     delay(50);

     if(DebugEnable){Serial.println(F("new clock data"));
     Serial.println(obtainTime());}
    // setRTC();
      break;
      

    } else {
      if(DebugEnable){Serial.println(F("Couldn't get network time, retrying in 15s."));}
      delay(15000L);
    }
  }
//  if(DebugEnable){Serial.println(F("Retrieving time again as a string"));}
//  String time = modem.getGSMDateTime(DATE_FULL);
//  DBG("Current Network Time:", time);
//

#endif

#if TINY_GSM_TEST_TEMPERATURE && defined TINY_GSM_MODEM_HAS_TEMPERATURE
  temp = modem.getTemperature();
  DBG("Chip temperature:", temp);
#endif


//delay(5000);

  }




  void GPRSconnect(){
  digitalWrite(CommsSwitch, HIGH);
  if (modem.isNetworkConnected()) {  if(DebugEnable){Serial.println(F("Network connected"));} }
   DBG("Connecting to", apn);
  if (!modem.gprsConnect(apn, gprsUser, gprsPass)) {
    delay(5000);
    return;
  }

//  bool res = modem.isGprsConnected();
//  DBG("GPRS status:", res ? "connected" : "not connected");
  }

  void modemPowerOff(){
    
         // delay(2000L);
          modem.gprsDisconnect();
          //delay(4000L);
          if (!modem.isGprsConnected()) {
            if(DebugEnable){Serial.println(F("GPRS disconnected"));}
          } else {
            if(DebugEnable){Serial.println(F("GPRS disconnect: Failed."));}
          }       
        
        
          // Try to power-off (modem may decide to restart automatically)
          // To turn off modem completely, please use Reset/Enable pins
          modem.poweroff();
          if(DebugEnable){Serial.println(F("Poweroff."));}
          delay(500);
          digitalWrite(CommsSwitch, LOW);
        
    }
   
//******************************************************************************



  


void setup() {
  
  Serial.begin(115200); Serial3.begin(9600);  mySerial.begin(9600);  
  //Serial1.begin(115200);  
  Serial1.begin(9600);  
  
  
  pinMode(IandETempSwitch, OUTPUT);
  pinMode(pmsSwitch, OUTPUT);
  pinMode(Battery, INPUT);
  pinMode(CommsSwitch, OUTPUT);
  pinMode(configTrigger, INPUT);

  
  
  digitalWrite(IandETempSwitch, LOW); //switch IE temp sensor off, power saving mode
  digitalWrite(pmsSwitch, HIGH);// switch sensor off, power saving mode
  //digitalWrite(CommsSwitch, HIGH);
  digitalWrite(configTrigger, HIGH);
  delay(700);
  if(digitalRead(configTrigger) == LOW){DevSetup();}
  DevProperties();
  
   
//  if(DevRev ==RevA){ Serial1.begin(9600); Serial.print("Rev A "); }
//  else if(DevRev ==RevB){Serial1.begin(9600);  Serial.print("Rev B "); }
//  else if(DevRev ==RevC){ Serial1.begin(115200);   Serial.print("Rev C "); }

  
  BatteryVoltage();
 if(DebugEnable){Serial.println(F(""));} 
 

     enableSD();  
       
     modemInfo();
     //startGsm(CommsSwitch);
     readLocation(); 
     modemPowerOff();
     
}



void loop() {
 
  Check_pms();
 
  
}

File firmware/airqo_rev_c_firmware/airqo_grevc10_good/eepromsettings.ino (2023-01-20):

void DevSetup(){
  int doOnce = 0; boolean op = true; 
  //String channelId;  String devName;   String writeAPIKey;
  
 // boolean MobileOperator;  
  
  while(true){
  if (doOnce == 0){
  Serial.println(F("##################### WELCOME TO DEVICE CONFIGURATION. USE THE # AS DELIMETER. USE ^ TO ERASE. USE > TO SKIP ENTRY  #######################:")); 
  Serial.print(F("Do wish to reset EEPROM data(Y || N)")); 
  doOnce = 1;}
  {    
    if (Serial.available()){
    char c = Serial.read(); if (c == 'Y' || c == 'y' ) {
        Serial.println(F(" : Y"));
        Serial.println(F("Reseting EEPROM data")); 
        Serial.print(F("EEPROM length: ")); 
        Serial.println(EEPROM.length()); Serial.println(F("Wait please###"));
        for (int i = 0 ; i < EEPROM.length() ; i++) {
        //Serial.print(F("Reseting Address: ")); Serial.println(i);
        EEPROM.write(i, 0);
        }
        Serial.println(F("Reset Done"));
        doOnce = 0; break; }
        else if (c == 'N' || c == 'n' ) {Serial.println(F(" : N"));doOnce = 0; break;} 
        else {readString += c; } } 
    
    
 }}

   while(op){
  if (doOnce == 0){
  Serial.print(F("Do wish to configure Device communication params(Y || N)")); 
  doOnce = 1;}
  {    
    if (Serial.available()){
    char c = Serial.read(); if (c == 'Y' || c == 'y' ) {
        Serial.println(F(" : Y"));delay(50);
        readString = ""; doOnce = 0; op = true;  break; }
        else if (c == 'N' || c == 'n' ) {
           Serial.println(F(" : N"));
          Serial.println(F("Done"));
          op = false; 
           Serial.print(F("Device will restart in 5 seconds, dettach the config jumper. ")); delay(2000);
           Serial.print(F(" 5 ")); delay(1000);
           Serial.print(F(" 4 "));delay(1000);
           Serial.print(F(" 3 "));delay(1000);
           Serial.print(F(" 2 "));delay(1000);
           Serial.print(F(" 1 "));delay(1000);
           Serial.print(F(" Restarting "));delay(2000);
           asm volatile(" jmp 0");
          return;} 
        else {readString += c; } } 
    
    
 }}


  
  while(op){
  if (doOnce == 0){
  readString = "";   
  runx:
  Serial.print(F("Input Device Name(22 characters MAX):")); 
  doOnce = 1;}

  if (Serial.available()>0){
    Serial.flush();Serial.flush();
    char c = Serial.read(); if (c == '#') {   
      
      Serial.println(readString);    doOnce = 0;
      while(true){
      if (doOnce == 0){
      Serial.print(F("Do you wish to commit this entry(Y || N)"));     doOnce = 1;}
       
            if (Serial.available()>0){
            Serial.flush();Serial.flush();
            char c = Serial.read(); if (c == 'Y' || c == 'y' ) {
            Serial.println(" : Y");
            Serial.println(F("Commit Done"));
            DevName = readString;   doOnce = 0; readString= ""; writeString(1, DevName); delay(10);
            op = false;
            break;              }
            else if (c == 'N' || c == 'n' ) {
              Serial.println(F(" : N")); doOnce = 0; readString= "";
              Serial.println(F("Characters Erased, continue with input"));
              goto runx;
              } 
            //else  { if ((c == ' ') || (c =='\n')){
            else  { if( (c =='\n')){  
               }else{readString += c;}
              } }         
       }
    
    } else if (c == '^') {readString= "";Serial.println(F("Characters Erased, continue with input")); }
      else if (c == '>') {readString= "";Serial.println(F("Entry skipped")); doOnce = 0; readString= ""; break; }
      else {if ((c == ' ') || (c =='\n')){
      }else{readString += c;}
      }   }     
  }op = true;


  while(op){
  if (doOnce == 0){
  readString = "";   
  runx6:
  Serial.print(F("Input Device Generation(xx characters MAX):")); 
  doOnce = 1;}
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

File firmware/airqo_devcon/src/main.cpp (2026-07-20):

#include "Arduino.h"
#include "pins.h"
#include <Wire.h>
#include <SdFat.h>
#include <DHT.h>
#include <Adafruit_HTU21DF.h>
#include <Adafruit_INA219.h>
#include <Adafruit_PM25AQI.h>
#include <SoftwareSerial.h>
#include <ArduinoJson.h>

#define SENSOR_WARMUP_MS  2000
#define READ_INTERVAL_MS  5000UL
#define LOG_INTERVAL_MS   60000UL
#define LOG_FILENAME      "airqo.csv"

DHT              dht(DHT_PIN, DHT11);
Adafruit_HTU21DF sht25;
Adafruit_INA219  ina219;
SdFat            sd;
SoftwareSerial   pmsSerial2(PMS2_RX_PIN, PMS2_TX_PIN);
Adafruit_PM25AQI pms1, pms2;

bool sdReady = false;

// Per-field running accumulator
struct Accum {
  float    sum   = 0;

  uint16_t count = 0;

  void  add(float v)  { if (!isnan(v)) { sum += v; count++; } }
  float avg()   const { return count ? sum / count : NAN; }
  void  reset()       { sum = 0; count = 0; }
} a_dht_temp, a_dht_hum,                          // DHT11
  a_sht_temp, a_sht_hum,                          // SHT25
  a_bus_v, a_shunt_mv, a_current_ma, a_power_mw,  // INA219
  a_pms1_pm1, a_pms1_pm25, a_pms1_pm10,           // PMS5003 sensor 1
  a_pms2_pm1, a_pms2_pm25, a_pms2_pm10;           // PMS5003 sensor 2

unsigned long lastReadTime = 0;
unsigned long lastLogTime  = 0;

// Latest PMS frames — updated every loop()
PM25_AQI_Data pmsData;
uint16_t pms1_pm1 = 0, pms1_pm25 = 0, pms1_pm10 = 0;
uint16_t pms2_pm1 = 0, pms2_pm25 = 0, pms2_pm10 = 0;
bool     pms1_valid = false, pms2_valid = false;

// Print value to SD file, or blank on NaN, then optional comma
static void csvField(SdFile& f, Accum& a, bool last = false) {
  float v = a.avg();
  if (!isnan(v)) f.print(v, 2);
  if (!last) f.print(',');
  a.reset();
}

void writeAvgToSD() {
  SdFile f;
  bool newFile = !sd.exists(LOG_FILENAME);
  if (!f.open(LOG_FILENAME, O_WRONLY | O_CREAT | O_AT_END)) {
    Serial.println(F("{\"sd_error\": \"failed to open log file\"}"));
    return;
  }
  if (newFile) {
    f.println(F("elapsed_s,"
                "dht_temp_c,dht_hum_pct,"
                "sht_temp_c,sht_hum_pct,"
                "bus_v,shunt_mv,current_ma,power_mw,"
                "pms1_pm1,pms1_pm25,pms1_pm10,"
                "pms2_pm1,pms2_pm25,pms2_pm10"));
  }
  f.print(millis() / 1000UL); f.print(',');
  csvField(f, a_dht_temp);   csvField(f, a_dht_hum);
  csvField(f, a_sht_temp);   csvField(f, a_sht_hum);
  csvField(f, a_bus_v);      csvField(f, a_shunt_mv);
  csvField(f, a_current_ma); csvField(f, a_power_mw);
  csvField(f, a_pms1_pm1);   csvField(f, a_pms1_pm25); csvField(f, a_pms1_pm10);
  csvField(f, a_pms2_pm1);   csvField(f, a_pms2_pm25); csvField(f, a_pms2_pm10, true);
  f.println();
  f.close();
}

void setup() {
  Serial.begin(115200);
  while (!Serial) { yield(); }

  pinMode(SENSOR_POWER_PIN, OUTPUT);
  digitalWrite(SENSOR_POWER_PIN, HIGH);
  pinMode(PMS_POWER_PIN, OUTPUT);
  digitalWrite(PMS_POWER_PIN, HIGH);
  delay(SENSOR_WARMUP_MS);

  dht.begin();

  if (!sht25.begin()) {
    JsonDocument err; err["error"] = "SHT25 not found - check wiring";
    serializeJsonPretty(err, Serial); Serial.println();
  }
  if (!ina219.begin()) {
    JsonDocument err; err["error"] = "INA219 not found - check wiring";
    serializeJsonPretty(err, Serial); Serial.println();
  }
  Serial3.begin(9600);
  pmsSerial2.begin(9600);
  pms1.begin_UART(&Serial3);
  pms2.begin_UART(&pmsSerial2);

  if (!sd.begin(SD_CS_PIN)) {
    JsonDocument err; err["error"] = "SD card init failed - check wiring";
    serializeJsonPretty(err, Serial); Serial.println();
  } else {
    sdReady = true;
  }

  lastReadTime = millis();
  lastLogTime  = millis();
}

void loop() {
  unsigned long now = millis();

  // Drain PMS serial buffers every iteration — keep latest frame
  if (pms1.read(&pmsData)) {
    pms1_pm1 = pmsData.pm10_env; pms1_pm25 = pmsData.pm25_env; pms1_pm10 = pmsData.pm100_env;
    pms1_valid = true;
  }
  if (pms2.read(&pmsData)) {
    pms2_pm1 = pmsData.pm10_env; pms2_pm25 = pmsData.pm25_env; pms2_pm10 = pmsData.pm100_env;
    pms2_valid = true;
  }

  // Read sensors every READ_INTERVAL_MS
  if (now - lastReadTime >= READ_INTERVAL_MS) {
    lastReadTime = now;

    float dht_temp = dht.readTemperature();
    float dht_hum  = dht.readHumidity();
    float sht_temp = sht25.readTemperature();
    float sht_hum  = sht25.readHumidity();
    float bus_v    = ina219.getBusVoltage_V();
    float shunt_mv = ina219.getShuntVoltage_mV();
    float cur_ma   = ina219.getCurrent_mA();
    float pow_mw   = ina219.getPower_mW();

    a_dht_temp.add(dht_temp);  a_dht_hum.add(dht_hum);
    a_sht_temp.add(sht_temp);  a_sht_hum.add(sht_hum);
    a_bus_v.add(bus_v);        a_shunt_mv.add(shunt_mv);
    a_current_ma.add(cur_ma);  a_power_mw.add(pow_mw);

    // Snapshot latest PMS readings then clear the valid flag
    bool     s1ok = pms1_valid, s2ok = pms2_valid;
    uint16_t s1_pm1 = pms1_pm1, s1_pm25 = pms1_pm25, s1_pm10 = pms1_pm10;
    uint16_t s2_pm1 = pms2_pm1, s2_pm25 = pms2_pm25, s2_pm10 = pms2_pm10;
    pms1_valid = false; pms2_valid = false;

    if (s1ok) { a_pms1_pm1.add(s1_pm1); a_pms1_pm25.add(s1_pm25); a_pms1_pm10.add(s1_pm10); }
    if (s2ok) { a_pms2_pm1.add(s2_pm1); a_pms2_pm25.add(s2_pm25); a_pms2_pm10.add(s2_pm10); }

    // Print live reading as pretty JSON
    StaticJsonDocument<768> doc;

    JsonObject dht_obj = doc["dht11"].to<JsonObject>();
    if (isnan(dht_temp)) dht_obj["temperature_c"] = nullptr; else dht_obj["temperature_c"] = dht_temp;
    if (isnan(dht_hum))  dht_obj["humidity_pct"]  = nullptr; else dht_obj["humidity_pct"]  = dht_hum;

    JsonObject sht_obj = doc["sht25"].to<JsonObject>();
    if (isnan(sht_temp)) sht_obj["temperature_c"] = nullptr; else sht_obj["temperature_c"] = sht_temp;
    if (isnan(sht_hum))  sht_obj["humidity_pct"]  = nullptr; else sht_obj["humidity_pct"]  = sht_hum;

    JsonObject ina_obj = doc["ina219"].to<JsonObject>();
    ina_obj["bus_voltage_v"]    = bus_v;
    ina_obj["shunt_voltage_mv"] = shunt_mv;
    ina_obj["current_ma"]       = cur_ma;
    ina_obj["power_mw"]         = pow_mw;

    JsonObject p1 = doc["pms5003_s1"].to<JsonObject>();
    if (s1ok) { p1["pm1_ug_m3"] = s1_pm1;  p1["pm25_ug_m3"] = s1_pm25; p1["pm10_ug_m3"] = s1_pm10; }
    else      { p1["pm1_ug_m3"] = nullptr; p1["pm25_ug_m3"] = nullptr; p1["pm10_ug_m3"] = nullptr; }

    JsonObject p2 = doc["pms5003_s2"].to<JsonObject>();
    if (s2ok) { p2["pm1_ug_m3"] = s2_pm1;  p2["pm25_ug_m3"] = s2_pm25; p2["pm10_ug_m3"] = s2_pm10; }
    else      { p2["pm1_ug_m3"] = nullptr; p2["pm25_ug_m3"] = nullptr; p2["pm10_ug_m3"] = nullptr; }

    serializeJsonPretty(doc, Serial);
    Serial.println();
  }

  // Log minutely average to SD card
  if (sdReady && (now - lastLogTime >= LOG_INTERVAL_MS)) {
    lastLogTime = now;
    writeAvgToSD();
  }
}

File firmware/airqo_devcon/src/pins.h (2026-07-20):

#ifndef PINS_H
#define PINS_H

#define SENSOR_POWER_PIN A8  // MOSFET gate — powers DHT11, SHT25, INA219
#define DHT_PIN          A3  // DHT11 data pin
#define SD_CS_PIN        28  // SD card chip select

#define PMS_POWER_PIN    A2  // MOSFET gate — powers both PMS5003 sensors
#define PMS2_RX_PIN      12  // SoftwareSerial RX — PMS5003 sensor 2 TX
#define PMS2_TX_PIN      13  // SoftwareSerial TX — PMS5003 sensor 2 RX

#endif  // PINS_H

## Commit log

2022-10-17 Add files via upload
    These are the design files for Rev C enclosure. these are .3MF files that can be sliced with PRUSA SCLICER .
    Recommended print setings:
    0.2mm layer height
    prusamnet PETG
    [gen5revc-battery-cover v3.3MF, gen5revc-enclosure v3.3MF, gen5revc-enclosure-body v3.3MF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]
2022-11-25 Short description This is a simple firmware for testing the operation of PMS5003 sensors in the airqo Gen5 devices.
    [main.cpp]
2022-11-25 Short Description firmware to test the pm sensor operation Long Description This firmware tests both pm sensors, take a user specified number of samples and averages the readings from the sensor valu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
    [main.cpp]
2023-01-21 a reorganization of the folder structure to easily guide development of hardware projects
    [gen5revc-battery-cover v3.3MF, gen5revc-enclosure v3.3MF, gen5revc-enclosure-body v3.3MF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]
2023-01-28 changed folder name for revC tosomething shoter and acceptable
    [gen5revc-battery-cover v3.3MF, gen5revc-enclosure v3.3MF, gen5revc-enclosure-body v3.3MF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]
2023-01-28 changed folder names to shoter names
    [gen5revc-battery-cover v3.3MF, gen5revc-enclosure v3.3MF, gen5revc-enclosure-body v3.3MF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]
2023-02-09 eddited the sensor list
2023-05-30 resolved the folder nesting
    [main.cpp]
2023-06-23 added structure for PMS sensor sampling
2023-06-23 used sample count variable instead of fixed value 60
    [main.cpp]
2023-07-22 created a Kicad project for Lorawan prototype work in progress
    [Lorawan_Prototype_v1.kicad_pcb, Lorawan_Prototype_v1.kicad_sch]
2023-07-26 added 3.3v regulator and other suppport schematics- still a work in progress
    [Lorawan_Prototype_v1.kicad_sch]
2023-07-29 categorized power sections
    [Lorawan_Prototype_v1.kicad_pcb]
2023-08-24 ive had to make a few design cahnges and hence will be removing the most recent commits and update them witht he latest designs that i am confidently going with
    [Lorawan_Prototype_v1.kicad_pcb, Lorawan_Prototype_v1.kicad_sch]
2023-08-24 here is the updated design utilizing a 64 pin LQFP package of the stm32f103
    [BOARDOUTLINE.DXF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]
2023-08-24 Code allowing bi-directional communication while utilizing the thingspeak mqtt broker
    [mqtt_thingspeak_bi_directional_communication.ino]
2023-10-28 naming _edits
    [Lorawan_prototype_v1.1-B_Cu.gbr, Lorawan_prototype_v1.1-B_Mask.gbr, Lorawan_prototype_v1.1-B_Paste.gbr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]
2023-11-04 naming_convention for hardware
    [boardoutline.DXF, gen5revc_battery_cover_v3.3MF, gen5revc_enclosure_body_v3.3MF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]
2023-11-11 complete neaming convention
    [main_body.stl, main_cover.stl, pm_sensor_holder.stl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]
2023-11-23 reorganized the folders so as to have a single hardware and firmware folder, enclosure designs have been moved to harware folder, and all firmware has been moved to firmware folder
    [main_body.stl, main_cover.stl, pm_sensor_holder.stl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]
2026-06-08 docs: add VitePress documentation site with AirQo branding
    - Set up VitePress v1.6.4 as the documentation framework
    - Migrated all content from Notion wiki and BAM Data Logger PDF manual
    - Structured docs into sections: Device, Firmware, Deployment, Maintenance, Data Logger
    - Applied AirQo brand styling (#145DFF, Inter font, logo, favicon)
    - Added hero home page with feature cards and quick-start actions
    - Included 30+ images extracted from Notion HTML export and PDF manual
    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
2026-07-20 firmware: add AirQo DevCon multi-sensor node (Arduino Mega 2560)
    Adds a full PlatformIO project for the AirQo DevCon sensor node:
    Sensors integrated:
    - DHT11 — temperature & relative humidity (digital)
    - SHT25 (HTU21DF) — temperature & relative humidity (I²C)
    - INA219 — bus voltage, shunt voltage, current, power (I²C)
    - PMS5003 ×2 — PM1.0 / PM2.5 / PM10 particulate matter (UART)
    Firmware features:
    - 5-second sensor polling with running average accumulator
    - Live pretty-printed JSON output over Serial (115200 baud)
    - Per-minute averaged CSV rows written to SD card
    - JSON error reporting for missing sensors or SD failures
    Target board: Arduino Mega 2560 (PlatformIO: atmelavr/mega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
    [main.cpp, pins.h]
2026-07-20 Potential fix for pull request finding
    [main.cpp]
